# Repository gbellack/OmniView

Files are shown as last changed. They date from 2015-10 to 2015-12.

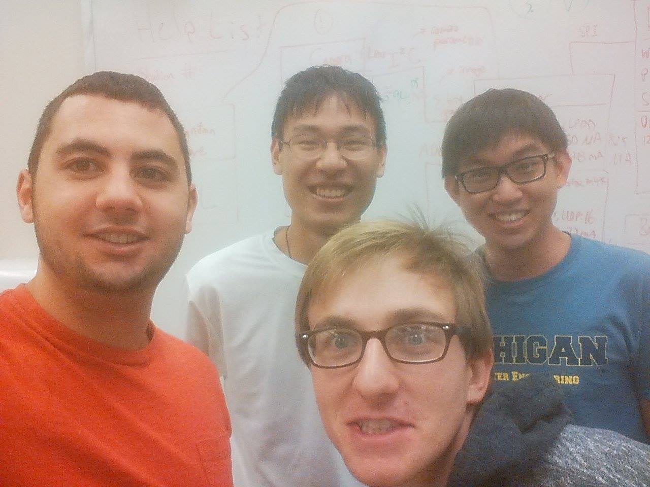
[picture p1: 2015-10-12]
face_software/testPics/fourFaces.jpg

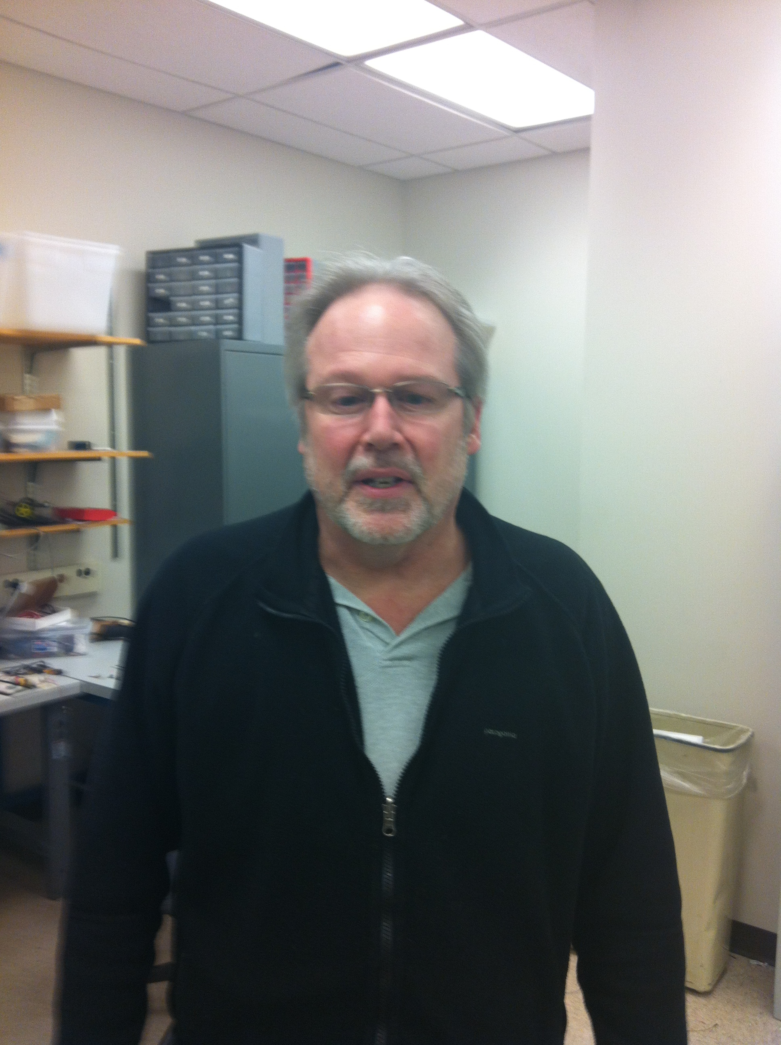
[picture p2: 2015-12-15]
face_software/training/Matthew Smith/IMG_0660.JPG

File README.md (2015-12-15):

#OmniView

##Hardware
--------
1. Texas Instruments CC3200 MCU

##Installation
1. You will need Code Composer Studio (CCS) version 6.1.1 installed on your computer. You can download this from TI's website. You will need to enter some credentials and get approved to be able to download the software.
2. You will be prompted to select modules that you want CCS to download. Please install the CC3200 package under SimpleLink Wifi Support tools.
3. After installing CCS, please install the CC3200 SDK from Texas Instruments.
4. If you launch Code Composer Studio for the first time, it will prompt you for a workspace directory. Feel free to pick a directory that you would like to work off.
5. Here comes the fun part. Please install GitHub for Windows. You will need this to pull the CCS project from this repository.  
// TODO

You should be able to build and run the project once all these are set up. 

###Flashing the program via UniFlash

If you would like to flash the program onto the Launchpad, you will need a seaparate program called Uniflash by Texas Instruments. Go ahead and download it from here and continue to follow the steps below. If you would not like to do so, you may skip them.
Credits to: [Texas Instruments Uniflash Wiki page](http://processors.wiki.ti.com/index.php/UniFlash_Quick_Start_Guide)

### Folder/File description
1. omniview/main.c : This is where the main program lies. All things related to scheduling is done here.

2. omniview/mode.c: This file contains the two modes that the facial recognition is capable of doing, as well as module initialization functions. All modules (display, camera etc.) are included and used here. Primary mode basically takes an image every second and returns the name of the person in the image.

3. omniview/pinmux.c/h : This is where we specify which pins are being used for certain protocols by the program.

4. omniview/modules folder: This stores all the modules/component libraries. More on that later...

5. omniview/modules/display/display.c/h: This file implements the driver for the display. It provides a good interface for the OLED display that we are using.

6. omniview/modules/display/buffer.c: This file contains the display buffer. The reason why we have this in a separate file is because the display had initialization values that we wanted to keep, and by adding this huge buffer definition in our display function, it will make that file really big and hard to read. Hence, we decided to split it into a separate file and link it up.

7. omniview/modules/display/font.c: This file contains the font settings for text on our OLED display. For the same reason above, we decided to move it to a separate file.

8. omniview/modules/interrupts/button_interrupt.c/h: These files contain interfaces for triggering a GPIO interrupt via one of our buttons. Some of the macros are linked to other macros defined by Texas Instruments.

9. omniview/modules/interrupts/timer_interrupt.c/h: These files contain interfaces for triggering a timer interrupt. This is mainly used by the microphone interface for audio recording purposes during secondary mode.

10. omniview/modules/microphone/microphone.c/h: These files contain the interfaces for the microphone.

11. omniview/modules/networking/tcp_network.c/h: These files contain the TCP networking interface required to send data/files across the network (or in our case, interact with our server).

12. omniview/modules/camera/mt9d111.c/h: These files contain the driver for the camera model that we are currently using.

13. omniview/modules/face_software/faceRec.cpp: This file contains the main server loop as well as several functions that help it in running.

14. omniview/modules/face_software/tcpClient.c/h: Houses the server side networking code used to communicate (by TCP) with the embedded device.

15. omniview/modules/face_software/wav_transcribe.py: Called by the main facial recognition loop. Communicates with google’s speech to text recognition server. Sends a string to parseName and receives names back. Sends names back to facial recognition main.

16. omniview/modules/face_software/parseName.py: Uses a natural language processing toolkit to process the string. Returns the names identified by the algorithm to wav_transcribe.

17. omniview/modules/face_software/training: Database holding our folders of faces. Test pic gets compared to this database to find the most similar face. A folder is created for each unique person in our dataset. The folder, named after the person, houses the pictures of the person inside.
Eg. omniview/modules/face_software/training/john_connolly/john1.jpg  is the first picture of John Connolly in the database.

###Speech Recognition
Please READ:
1. Make sure you have PyAudio installed.
2. All the examples are in the speech_recognition file.

###Version Control for Code Composer Studio Project
The .gitignore file on this repository should do the trick, but please:  
  
DO commit and push:  
1. .ccsproject  
2. .cproject  
3. .project  
4. .settings folder  
5. makefile.defs (if using SYS/BIOS)  

DO NOT commit and push:    
1. Release/*  
2. config/*  
3. .launches/  
4. .xdchelp  

Credits to: [Texas Instruments Wiki page](http://processors.wiki.ti.com/index.php/Source_control_with_CCS)  

##Support
Please feel free to contact any of us if you have any questions or concerns.

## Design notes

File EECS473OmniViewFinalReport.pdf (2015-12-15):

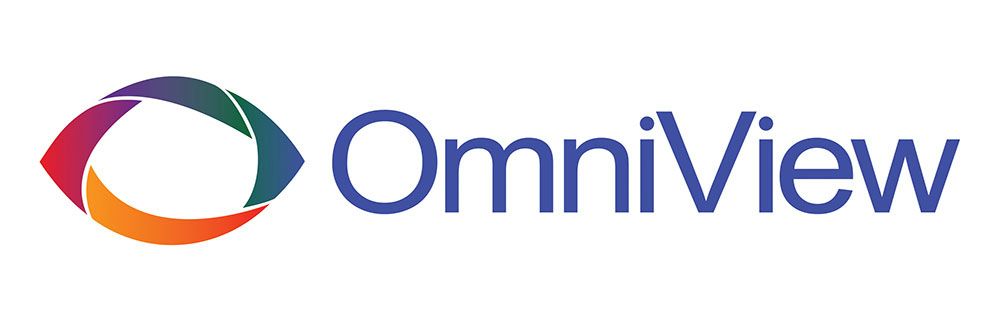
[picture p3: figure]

# Final Report

To: | Mark Brehob Eric Kumpf
From: | Garrison Bellack (gbellack), Computer Engineer John Connolly (johnconn), Computer Engineer Loren Wang (wloren), Computer Engineer Tzu-Fei Yu (tzufeiy), Electrical Engineer Zheng Hao Tan (tanzhao), Computer Engineer

Date: December 14, 2015

# OmniView Face Recognition Glasses EECS 473 Fall 2015

I. Introduction and overview of project

Foreword
Since the beginning of human interaction, names have played a crucial role. Names serve as an identifier for a person, and without them people have no identity. In our modern society dominated by social media, interactions have become more frequent but less substantial, which has sparked a phenomenon where it has become harder to remember people’s names. One of the most important things in the social world is remembering people's names. To quote Dale Carnegie, “A person’s name is to him or her the sweetest and most important sound in any language”. However, too often we can’t remember the names of people we meet, even after multiple interactions.

We decided to address this issue by applying it alongside the recent surge in popularity of smart, wearable tech. We created OmniView, a pair of smart glasses with facial recognition capabilities, that can serve as an aid to the user in identifying a person and their name. The purpose of this report is to provide a detailed description of our project, as well as detail our experiences and what we have learned. This report will be written with concurrent engineers and managers in mind to ensure the results of our project are accessible to a larger audience.

Summary
At the College of Engineering Design Expo, we proudly presented OmniView with its two modes, primary and secondary. Primary mode is the normal mode of operation which displays people's names. Secondary mode adds new people to the database by recording their introduction then storing their parsed name along with their picture. However, due to how loud it was in the Expo, we could only demonstrate primary mode. We would give OmniView to people who stopped by our booth and as soon as they put it on, they could tell each of the group members’ names by looking at us. OmniView is innately demoable and people were very impressed by the project.

We used open source facial recognition software to identify people. The project, OpenBR, is available for download . To parse people’s names we first used Google’s speech to text api to

1 | 2

1 http://openbiometrics.org/
2 https://www.google.com/intl/en/chrome/demos/speech.html

# OmniView Face Recognition Glasses EECS 473

## Fall 2015

convert the audio into words. From there we used NLTK (Natural Language ToolKit) to detect

3
if there were any names in the words spoken.

This report describes the resources used and tasks completed for this project. Below are our goals for OmniView. All Milestones were met.

Design Criteria | Importance | Likelihood | Finished State

Facial recognition correctly determines new/old faces >

80% | Fundamental | Will | Yes. > 90% facial recognition
OLED displays name and info quickly enough such that user will not have to wait | Fundamental | Expect | Yes. Recognition in < .20 seconds
Battery life > 1 hour | Important | Will | Yes. Battery life > 5 hours
User has simple/efficient control of the glasses | Important | Will | Yes. Single push button control
Weight should not exceed such a limit that it will cause pain or discomfort to the user | Important | Expect | Mostly. Initial prototype had unbalanced weight
Software & Microphone are able to capture and person’s name | Optional | Stretch | Mostly. Next iteration will have a more sensitive microphone.
Flexible PCB | Optional | Stretch | No. Decided not to use a flexible PCB.

3 http://www.nltk.org/

# OmniView Face Recognition Glasses EECS 473

## Fall 2015

II. Description of project
Our goal was to create a device that aids people in remembering names. We believe this product could see widespread casual use, but would be especially useful for people with a bad memory or those entering a large/new social environment such as school, work or a party. We believe it will be used in these situations because the price of not remembering someone’s name can be quite high. Especially in business, where having positive work relationships is critical, a lapse in social graces could mean a very real financial setback.

We thought that the optimal way to accomplish this goal is through a device like Google Glass. A small camera can be used to take pictures of whomever the device wearer is looking at, and a display near the eye can be used to alert the wearer of the person’s name. From this idea, OmniView was born.

OmniView is a pair of glasses with a camera that can instantly display the name of the person you are looking at. Using an existing database of facename pairs such as a school registry, the glasses could take a picture of the person you are looking at and send the data to a server where the person’s unique facial structure is analyzed. The server would then return the name of the matching entry, showing the name of the person in front of you on a display in the corner of your vision. A new entry could also be dynamically created by taking a picture and sending that information to the server along with accompanying audio of their introduction or only sending the picture and adding their name to the server later. This sort of solution could be very helpful in new social settings, where it can be difficult to remember the names of many new people, or in scenarios where an old acquaintance’s name is suddenly forgotten.

With our monetary and time budgets, we have accepted that it is impossible to make OmniView subtle enough to be unnoticeable. In the end, we had great success on the technical side of our project, and succeeded in implementing all of the functionality we sought to. Even with this success, our work is not done. With wearable devices, there are important concerns beyond the technical details. It is not yet socially acceptable to walk around wearing a piece of tech on your face. While we thought that OmniView could be immensely valuable if executed properly, we are also worried about the complexity of the project. The idea is in a lot of ways, a minimalist Google Glass, and so we were worried that we wouldn’t be able to complete all of our goals in the timeframe allotted. Even Google has run into issues with their wearable product. The bulkiness of Glass is an issue that prevents widespread use of the device. It is far too obvious that someone is wearing Glass, and this bothers people. Those some complaints can be applied to OmniView – our device is too heavy and intrusive to be comfortably worn. All of this led us to

# OmniView Face Recognition Glasses EECS 473

## Fall 2015

determine that OmniView as a technical project is feasible, but OmniView as a commercial product is not feasible yet.

ii. Describe the system architecture, including a detailed block diagram (not drawn by hand) of the system including peripherals, processors and the like. Give an explanation of how the architecture works – what the function of each of the devices is and how you communicate to them.

OmniView is comprised of a few submodules: A camera, a microcontroller, a display, a microphone, and a web server. The interactions between these five components powers OmniView, and can be seen in Figure 1. At a high level, the application runs by taking a picture, sending it to the web server, waiting to receive a response from the web server, and writing that response onto the display.

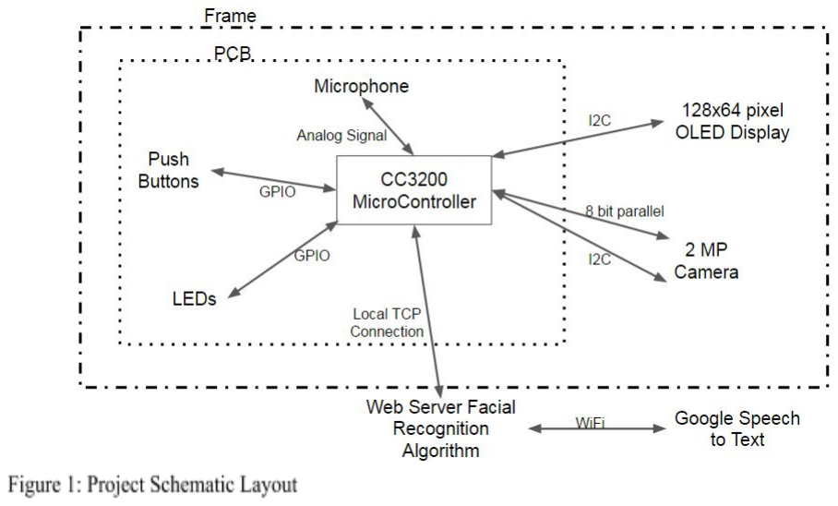
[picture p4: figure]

The first module that will be discussed is the camera. The camera is the lynchpin of OmniView; it provides the images that OmniView compares to the facename database, so that the application can determine the names of people the device wearer is interacting with. We chose to use the MT9D111 camera for this application. This camera has 2 Megapixel image quality, and communicates with the microcontroller through I2C and an 8-bit parallel databus. The I2C line is used to configure the camera, while the 8-bit parallel bus is used to transfer the

# OmniView Face Recognition Glasses EECS 473 Fall 2015

actual image from camera to microcontroller. The microcontroller polls the camera once every two seconds, receiving a fresh image and then sending it to the web server at these times.

The web server is used to perform the facial recognition algorithm and query the database of facename pairs. Using an external server and database allows us to reduce the amount of computations needed to be performed by OmniView. This plays an important role in extending the battery life of the application. Hosting the facial recognition algorithm on the server also allowed us to run the application loop very quickly. This is because the processor of the server is much better than that of our device. We relied on an opensource software for our facial recognition, with good results. Facial recognition using openBR[1], an opensource image processing library, was about 85% accurate. openBR uses the eigenfaces algorithm, a derivative of PCA (principle component analysis) method of machine learning to recognize the faces. The server code starts by initializing all the pictures in the existing database in a process known as “enrollment”. This extracts the main features of every picture. Doing this enrollment process before communicating with the device allows us save an extreme amount of time during our main application loop, allowing us to run at an O(1) speed. This is to say that the number of pictures in the database increases the initialization time of the algorithm, but has very little effect on the main loop. Once this process is done, the server connects to the TCP socket initialized by the embedded device. With a wireless connection established, the server can now receive a picture. The picture is saved onto the server, and also enrolled by the algorithm. This allows it to be compared with the existing pictures in the database, and a similarity score is assigned to each pair. The name of the face that was closest to that of the new picture is then sent through the TCP connection back to the device.

The communication between the server and microcontroller is conducted using WiFi. This is done for two reasons: it expands the maximum communication distance between the server and the device, and it allows for a higher throughput of data. Images are fairly data intensive, and we want the latency between an image sent to the server and the corresponding text sent back to the microcontroller to be as short as possible. Using WiFi does introduce at least one added layer of complexity to the device: the registering of the device as a station in a network. Instead of creating a dedicated user interface on the glasses for setting up connectivity, we instead allow for OmniView to be connected to as an access point, and communicate with a user’s personal computer. Through this method, OmniView can be registered on the network through the use of a personal computer.

# OmniView Face Recognition Glasses EECS 473 Fall 2015

We chose to use TI’s CC3200 microcontroller as the onboard processor for OmniView. This microcontroller has a dedicated core that implements the WiFi WLAN and TCP/IP stacks. It also has an onchip 80 MHz Cortex M4 processor to perform other application logic and interface with peripherals. The microcontroller includes 2 UART modules, 1 SPI module, 1 I2C module, and an 8-bit parallel camera interface. We decided on the TI CC3200 because it has built in support for a 2 megapixel camera and a core that handles the WiFi protocol. OmniView is very space constrained, because it is worn on the face. Having a chip that can handle WiFi and natively communicate with a camera is the best solution for a spaceconstrained system, because it allows us to avoid introducing even more chips into the system to handle WiFi and camera communication. Another important reason for using a chip that includes everything we needed is that the vendor (Texas Instruments) provided sample code for implementing WiFi on the microcontroller. We relied heavily on this sample code during the course of the project in order to reduce development time. If we used a dedicated WiFi module, it is unlikely that we would be able to find sample code ported to our specific microcontroller.

We decided to use an Organic Light Emitting Diode (OLED) display as an interface to the user. This is the medium through which OmniView shows the device wearer people’s names. OLED displays require less power than other common display solutions. OLED displays only draw power based on the sections of the display that are lit. Another important factor is weight of the display; OLED displays are lighter than LCDs. Communication between the display and the microcontroller is done via a common serial protocol. OLED displays in our size range support I2C, SPI, or both. Our system requirements make it impossible to use SPI as means of communication, simply because we do not have enough pins. For this reason, we use the same I2C port that the camera uses to communicate to the display.

# OmniView Face Recognition Glasses EECS 473 Fall 2015

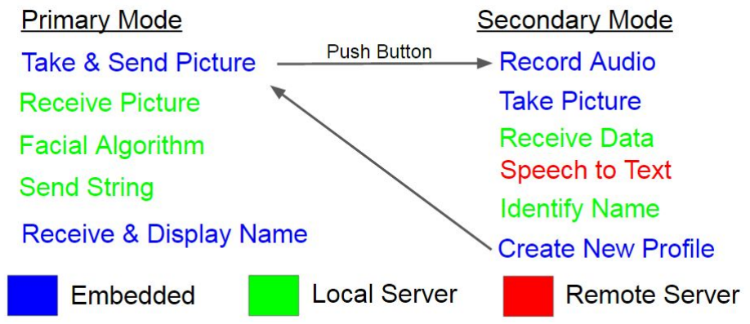
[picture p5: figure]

The microphone and push button are the parts of the system used to implement the secondary mode of operation for OmniView. The secondary mode of operation is used to dynamically add a facename pair to the database. The push button is used by the user to switch OmniView from primary to secondary operation. Once secondary mode is activated, the device then grabs data from the microphone for 10 seconds, and then captures an image of who the device wearer is looking at. OmniView then transmits that data to the web server. The web server then parses that microphone data and determines which name was spoken during that period and associates it with the image that was sent with the microphone data. Parsing text from speech is a nontrivial task, and for this reason, we employed Google Speech[3] to convert the data from audio to text. After this was completed, the text was piped to a natural language toolkit (NLTK) that was hosted on the external server. This allowed us to pick out any proper nouns that existed in the sentence. These nouns were assumed to be the name of the person in the picture, and a folder was created for this new entry.

OmniView Face Recognition Glasses | EECS 473 Fall 2015
III. | Milestones, schedule and budget

We stuck to our original schedule pretty well through the project development cycle. There were multiple tasks that were shifted around the timeline, such as ordering components, which we wanted to order by late September but did not do so until mid November. This was rather trivial as we didn’t know what we need on our PCB to get the components to work. We also started working on the microphone about a week in advance, since we were fairly certain that a stretch goal is plausible based on our progress before Thanksgiving break. We also added a few more tasks, such as spinning out a separate sandwich board just in case we needed it. We provided more details about this below.

These were the milestone deliverables that we signed up for during the project proposal stage:

Milestone 1:

Tasks | Outcomes
Prototype is capable of displaying meaningful text on the OLED display. | On time.
Basic WiFi module is able to send/receive data from server. | On time.
PCB schematic design should be done. | We finished the PCB schematic design about 24 hours earlier, but the peripheral board wasn’t done until 2 days later because we didn’t expect it to take so much time. We were kind of ambitious of getting this done by the time allocated.
The image recognition algorithm should already be implemented and able to show meaningful information. | This was mostly done by the time the project proposal was due.

# OmniView Face Recognition Glasses EECS 473 Fall 2015

Milestone 2:

Tasks | Outcomes
PCB should have been ordered by now. | We were about 24 hours late for this because we have having some doubts about our main board layout. Fortunately, we pushed this back and managed to fix them before we ordered them.
The OLED display and WiFi software should be finished with only minor bugs left. | On time.
Have decided on whether we want to implement functionalities related to the microphone. | On time.
Frame of glasses should be 3D printed by now. | We decided to put this task till later because during this stage of the project, we were running into issues with our CC3200MOD package. We felt that we needed the extra manpower (Tzu-Fei) to come over and help us desolder/resolder until we can successfully program the board. We eventually finished it after 4 days from the proposed deadline.

OmniView Face Recognition Glasses | EECS 473 Fall 2015
IV. | Lessons learned
| What went well? What went poorly? If you could send a short memo back in time to your group when you first started, what would it say? What technical material do each of you feel you’ve learned from the project?

Over the course of the project, we have learned a lot about what it takes to create a complex embedded system. There is a design phase – where components and tools are chosen for the system. Next there is a development phase – where the idea begins to be actualized. Then comes the assembly phase – where each module is integrated into the finalized system. We learned a lot about the design and assembly phases of embedded system on the way to our finished project.

The most important lesson learned is that the design phase is the most important part of system implementation. There is a very real possibility that an idea will have to be completely reworked in the prototype phase when the engineer realizes that the design isn’t feasible. Every stage of the project needs to be properly thought out. If there is even a single mistake in the design, then at best it will be a few extra hours creating a workaround for the system to function. At worst, it could mean the creation of an entirely new system.

One prime example of a mistake in the design stage leading to enormous problems down the road is an issue we had with our printed circuit board (PCB). During the schematic design of the PCB, our engineers chose to go with a package that would save us space and simplify the design process significantly. This probably resulted in 8 manhours saved in the design of the schematic and layout of the PCB. However, that part is incredibly difficult to solder. The result was an added 40 manhours spent trying to solder this component to the PCB.

A few things went very well. Using components supported by our vendor, Texas Instruments, sped up some areas of development significantly. An important reason for choosing the camera that we did is because TI has sample code for interacting with this device. Cameras are relatively complex, and choosing to use a camera that had the interfacing done for us was a huge boon. Having everything incorporated into our microcontroller was a major factor in our completing the software development on time. This allowed us to spend more time working through the unexpected issues that arose in the project, such as the PCB soldering issue described above. Another such unexpected issue was the difficulty we had working with TI’s code. While there was plenty of sample code provided for us, it was extremely difficult to follow, and some of the

# OmniView Face Recognition Glasses EECS 473 Fall 2015

sample applications TI are not well documented. For instance, one sample application instructs users to use “the browser of her choice” to connect to the microcontroller. We have found that Chrome, Firefox, and Internet Explorer are not compatible with this sample application, and when we tried to use these browsers the sample application failed. It was only through many hours of trial and error that we determined Safari to be the only browser that was compatible with the microcontroller and sample application.

We have gained a wide variety of skills from software to hardware development through the creation of OmniView. Several of our group members are now proficient in the eagle CAD tool. Beyond that, these group members have a much more solid theoretical understanding of the best practices involved with circuit board layout. We also needed to lay out a 50 ohm impedance trace for OmniView’s antenna, which was a valuable experience and gave us some insight on the different factors that affect trace impedance at very high frequencies. Another hardware related skill improved upon in this project is soldering of surface mount components. We had two PCBs to populate, with a wide variety of packages, some of them extremely difficult to solder. The positive to this struggle is that several of our team members are now extremely proficient in soldering a wide variety of surface mount components. Our group has gained experience in using large open source tools through this project as well. We used several open source tools, including openBR[1], for image analysis, and Google Speech[3] for audio processing. This project has taught us how to integrate these tools into an existing application.

The most important thing that we learned in this project is system design and architecture. In our careers as students at the university, we have never had the opportunity to design a system from top to bottom like we have in this course. The project idea and implementation are entirely up to us. Designing a system with both hardware and software components from scratch is a very difficult thing to do, because of the numerous unforeseen difficulties that arise in system design. One such difficulty is circuit board fabrication. Designing a circuit board with a CAD tool is easy enough, but fabricating the board is another matter. Usually circuit board fabrication will cost at least $100, and it takes at least a week to receive the board after an order. From a software perspective, the system becomes very complex, and larger than the software projects students are accustomed to in their classes. This project gave us experience in managing such a large system.

If we could send a memo back in time to our group, the memo would detail some architecture changes that should be made. Our choice of processor is currently in a quad flat nolead package (QFN). We made this decision because it simplified the schematic, but it raised the difficulty of our soldering job by an order of magnitude. This letter would tell our group to spend the extra

# OmniView Face Recognition Glasses EECS 473 Fall 2015

few hours using a different part in the schematic, so that we would not have to spend 50 hours soldering. In addition, the letter would detail spending a bit more time on the architecture of the system. The chip that we used, TI’s CC3200, ended up being very difficult to work with. In hindsight, it might have been worth choosing a chip from a different vendor, because of the huge amount of difficulty that we had dealing with Texas Instruments.

# OmniView Face Recognition Glasses EECS 473 Fall 2015

V. Contributions of each member of team
Team Member | Contributions | Effort
Garrison Bellack | In the early phase of the project, Garrison helped Loren in bringing up the facial recognition software on the server side. He implemented some of the TCP networking code. He then did most of the integration tasks as different components were added to the project. In other words, the interfaces were written for him, then he integrated them and debugged it. Most of the software refinements (timing constraints and requirements) during the later stage were handled by him and Loren. | 20%
John Connolly | John and Tzu-Fei did the schematic design and board layout. John also helped out with surfacemount/soldering related work. After we got the board to be programmed, he helped develop the microphone interface. He also helped the team to debug camera issues (both large and small cameras). | 20%
Loren Wang | Loren was the main guy who did server side code for both facial recognition software and natural language processing via Google Speech. He also helped the team to debug camera issues (both large and small cameras). Most of the software refinements (timing constraints and requirements) during the later stage were handled by him and Garrison. | 20%
Tzu-Fei Yu | Tzu-Fei and John did the schematic design and board layout. Besides that, he joined Zheng Hao to order the components needed. He also helped us with surfacemount/soldering work and made the 3D-printed glasses from scratch. | 20%

# OmniView Face Recognition Glasses EECS 473

## Fall 2015

Zheng Hao Tan Zheng Hao helped in the initial board bring up and setting up the toolchain (IDE + flashing software). He then worked on the display interface and helped Tzu-Fei on part selection/ordering them. He then helped out with soldering work. Once we got the board programmed, he worked on both a timer interrupt and button (GPIO) interrupt interface. The timer interrupt interface is then used by John for microphone purposes.

20%

OmniView Face Recognition Glasses | EECS 473 Fall 2015
VI. | Cost of Manufacture

The quote had failed to estimate the price for the main system board at first. After a few trials, we have determined that the minimum trace was too small (0.01mm). By carefully scanning through the board layout and fixing the width of the trace and polygon, we successfully generated a quote. According to the table below, which shows the result of the quote, the total cost for populating the whole system is about $728 if we requested only one unit. In contrast, this is below the $1000 budget that was given to us for the project. If we had limited the amount of money spent on the prototyping phase, we could afford this cost. Unless we would like to have spare ones in case the board is accidently burnt, one of each board should satisfy our application. The limiting quantity is four, where the total price for both board is $1000.75, and this will exceed our budget, leaving no room for us to prototype it.

On the other hand, one of the downsides of this is that once a mistake is unintentionally made, there will be no room to make another iteration for the PCB. Additionally, the manufacturing time is a major factor since the given project developing time span is about three months. The 22 day processing and shipping time will take up almost ⅓ of our project schedule. Furthermore, the price of the board increases dramatically if we want a faster turnaround time. The minimum manufacturing period is 8 days, and the cost for both boards is $1972.82. This price is not feasible. Most of the expenses goes to the assembly category when processing time is long, and goes to both PCB manufacture and assembly when the time is short. As a result, with the given time and budget, it is more desirable not to go with this option. Even if time allows, one would save more money without having the board house to assemble the board but doing oneself. In general, this option is not reasonable.

OmniView Main Board

Days | Quantity | PCB ($) | Parts ($) | Assembly ($) | Total ($) | Unit Price ($)
22 | 1 | 57.81 | 77.43 | 290.34 | 425.57 | 425.57
22 | 2 | 57.81 | 101.13 | 308.86 | 467.79 | 233.9
22 | 4 | 110.61 | 148.42 | 345.89 | 604.93 | 151.23
8 | 1 | 696.76 | 77.43 | 435.51 | 1209.7 | 1209.7

# OmniView Face Recognition Glasses EECS 473 Fall 2015

OmniView Peripheral Board

Days | Quantity | PCB ($) | Parts ($) | Assembly ($) | Total ($) | Unit Price ($)
17 | 1 | 15.32 | 65.65 | 222.28 | 303.24 | 303.24
17 | 2 | 15.32 | 81.29 | 234.71 | 331.31 | 165.65
17 | 4 | 25.63 | 110.61 | 259.00 | 395.82 | 98.955
7 | 1 | 364.05 | 65.65 | 333.42 | 763.12 | 763.12

# OmniView Face Recognition Glasses EECS 473 Fall 2015

VII. Parts

Budget

The items and price are listed in the table below:

Item for prototyping | Quantity | Total Cost ($)
OLED display Breakout board | 4 | 78.00
TI CC3200 LAUNCHXL Development board | 2 | 66.98
TI CC3200 MOD Development board | 1 | 34.99
TI CC3200 Camera Booster Pack | 2 | 44.49
MT9D111 Camera Breakout | 2 | 33.2
Microphone Breakout | 1 | 7.95
Item used on final product | Quantity | Total Cost ($)
LDO regulators (3.3V, 2.8V, 1.8V) TPS79328DBVRG4 TPS79318DBVR TPS73733DCQ | 20 | Free
MT9D111 Camera (flex module) | 5 | 24.66
AVX 145602030000829 | 10 | 8.80
OLED Module | 4 | 25.23
PCB Main Board | 2 | 152.03
PCB Peripheral Board | 2 | 86.03
PCB Sandwich Board | 3 | 4.05
TI CC3200 MOD MCU | 5 | Free

OmniView Face Recognition Glasses | EECS 473 Fall 2015
TI CC3200R1M2RGC | 3 | 31.37
Glasses Frame | 2 | Free
Lens | 1 | 10.99
Passive components (Capacitors, Resistors, Inductor, LEDs, Cable, Connectors, ferrite beads, uFL connector, button switch, pin head, ribbon cable, wires, Amplifier MAX9814, Microphone electret CMA-4544PF-W) | | 90.00
Lipo Battery Charger | 3 | 23.85
Lipo Battery 850mAh | 2 | 19.90
Lipo Battery 500mAh | 1 | 7.95

The total expenditure for this project is $751.47.

# OmniView Face Recognition Glasses EECS 473 Fall 2015

VIII. References and citations

Our main repository is split into two sections, one of them is the firmware for the facial recognition glasses and the other is server side code. Here is a brief overview of how we laid out the main repository, as well as the files and interfaces for the components that we use.

omniview/main.c :

This file contains the main function and several initialization functions for the facial recognition glasses.

#define FACE_RECOGNITION_TASK_NAME "FaceRecognitionTask"

#define FACE_RECOGNITION_TASK_STACK_SIZE 8192

#define FACE_RECOGNITION_TASK_PRIORITY 2

// EFFECTS: Initializes the board.
static void InitializeBoard();

omniview/mode.c:

This file contains the two modes that the facial recognition is capable of doing, as well as module initialization functions. All modules (display, camera etc.) are included and used here. Primary mode basically takes an image every second and returns the name of the person in the image.

// EFFECTS: A freeRTOS task that runs the facial recognition mode. This periodic task is scheduled to run every second.
void FaceRecognitionMode(void *pvParameters);

omniview/pinmux.c:

This file is originally provided by Texas Instruments in their sample applications, and it contains the pin configuration and modes for the facial recognition glasses. We have modified it extensively to fit our pinout requirements.

// EFFECTS: Configures the pinout for this project.

# OmniView Face Recognition Glasses EECS 473

## Fall 2015

void PinMuxConfig(void);

omniview/modules/display/display.c + omniview/modules/display/display.h:

These files contains the OLED display interface.

#define SSD1306_I2C_ADDRESS 0x3C // 011 110+SA0+RW, SA0 is grounded.

/* PIN LAYOUT CONFIGURATIONS */

#define DISPLAY_RESET_PIN 0x10 /*gpio 28 for display reset */

/* OLED CONFIGURATIONS */

#define SSD1306_LCDWIDTH | 128 | /* Display width */

#define SSD1306_LCDHEIGHT | 64 | /* Display height */

#define SSD1306_SETCONTRAST | | 0x8100

#define SSD1306_DISPLAYALLON_RESUME | 0xA400

#define SSD1306_DISPLAYALLON | | 0xA500

#define SSD1306_NORMALDISPLAY | | 0xA600

#define SSD1306_INVERTDISPLAY | | 0xA700

#define SSD1306_DISPLAYOFF | | 0xAE00

#define SSD1306_DISPLAYON | | 0xAF00

#define SSD1306_SETDISPLAYOFFSET | | 0xD300

#define SSD1306_SETCOMPINS | | 0xDA00

#define SSD1306_SETVCOMDETECT | | 0xDB00

#define SSD1306_SETDISPLAYCLOCKDIV | 0xD500

#define SSD1306_SETPRECHARGE | | 0xD900

#define SSD1306_SETMULTIPLEX | | 0xA800

#define SSD1306_SETLOWCOLUMN | | 0x0000

# OmniView Face Recognition Glasses EECS 473

## Fall 2015

#define SSD1306_SETHIGHCOLUMN | 0x1000

#define SSD1306_SETSTARTLINE | 0x4000

#define SSD1306_MEMORYMODE | 0x2000

#define SSD1306_COLUMNADDR | 0x2100

#define SSD1306_PAGEADDR | 0x2200

#define SSD1306_COMSCANINC | 0xC000

#define SSD1306_COMSCANDEC | 0xC800

#define SSD1306_SEGREMAP | 0xA100

#define SSD1306_CHARGEPUMP | 0x8D00

#define SSD1306_EXTERNALVCC | 0x0100

#define SSD1306_SWITCHCAPVCC | 0x0200

/* SCROLLING DEFINES */
#define SSD1306_ACTIVATE_SCROLL | 0x2F00

#define SSD1306_DEACTIVATE_SCROLL | 0x2E00

#define SSD1306_SET_VERTICAL_SCROLL_AREA | 0xA300

#define SSD1306_RIGHT_HORIZONTAL_SCROLL | 0x2600

#define SSD1306_LEFT_HORIZONTAL_SCROLL | 0x2700

#define SSD1306_VERTICAL_AND_RIGHT_HORIZONTAL_SCROLL 0x2900 #define SSD1306_VERTICAL_AND_LEFT_HORIZONTAL_SCROLL 0x2A00

#define BLACK 0

#define WHITE 1

#define INVERSE 2

/* NAME PARAMETERS */
#define MAX_NAMES_ALLOCATED 5 #define MAX_NAME_LENGTH 15 #define NAME_TEXT_SIZE 1

# OmniView Face Recognition Glasses EECS 473 Fall 2015

#define TEXT_COLOR WHITE

/* Swaps the two values */
#define swap(a, b) { int16_t t = a; a = b; b = t; }

#define pgm_read_byte(addr) (*(const unsigned char *)(addr))

/* EFFECTS: Displays the name on the screen. */
extern void DisplayName(const char *firstName, const char *lastName);

/* Printing functions */
extern void ClearPrintDisplayLine(const char* str);
extern void DisplayPrint(const char *str);
extern void DisplayPrintLine(const char *str);
extern void PrintHelper(uint8_t c);

extern void FillRect(int16_t x, int16_t y, int16_t w, int16_t h, uint16_t color);
extern void DrawFastVLine(int16_t x, int16_t y, int16_t h, uint16_t color);
extern void DrawFastVLineInternal(int16_t x, int16_t __y, int16_t __h, uint16_t color); extern void DrawFastHLineInternal(int16_t x, int16_t y, int16_t w, uint16_t color);

extern void DrawChar(int16_t x, int16_t y, unsigned char c, uint16_t color, uint16_t bg, uint8_t size);
extern void SetCursor(int16_t x, int16_t y);
extern void SetTextColor(uint16_t c);
extern void SetTextSize(uint8_t s);
extern void SetTextWrap(uint8_t w);

/* EFFECTS: Changes to new line */ extern void IncrementLine();

/* REQUIRES: The reset pin.
* EFFECTS: Initializes the display pins.
*/
extern void InitializeDisplay();

/* EFFECTS: Send and receive the payload */

# OmniView Face Recognition Glasses EECS 473 Fall 2015

extern void Send(uint16_t payload);

/* Display */

/* EFFECTS: Clears the display. */
extern void ClearDisplay();

/* EFFECTS: Displays whatever that is stored in buffer */ extern void Display();

/* EFFECTS: Dims the display */
extern void Dim(int dim);

/* EFFECTS: Turns the display on. */ extern void DisplayOn();

/* EFFECTS:d Turns off the display. */ extern void DisplayOff();

/* Scrolling */

/* EFFECTS: Sets the scroll direction */
extern void StartScrollRight(uint8_t start, uint8_t stop);

extern void StartScrollLeft(uint8_t start, uint8_t stop);

extern void StopScroll();

/* REQUIRES: the x, y, and color.
* EFFECTS: Sets a pixel.
*/
extern void DrawPixel(int16_t x, int16_t y, uint16_t color);

omniview/modules/display/buffer.c:

# OmniView Face Recognition Glasses EECS 473

## Fall 2015

This file contains the display buffer. The reason why we have this in a separate file is because the display had initialization values that we wanted to keep, and by adding this huge buffer definition in our display function, it will make that file really big and hard to read. Hence, we decided to split it into a separate file and link it up.

static uint8_t buffer[SSD1306_LCDHEIGHT * SSD1306_LCDWIDTH / 8] = ….

omniview/modules/display/font.c:

This file contains the font settings for text on our OLED display. For the same reason above, we decided to move it to a separate file.

/* This file contains the font used in printed text. */

// Standard ASCII 5x7 font
static const unsigned char font[] = ...

omniview/modules/interrupts/button_interrupt.h + omniview/modules/interrupts/button_interrupt.c:

These files contain interfaces for triggering a GPIO interrupt via one of our buttons. Some of the macros are linked to other macros defined by Texas Instruments.

/* This is the amount of time to count to account for button debouncing. */
#define BUTTON_DEBOUNCE_THRESHOLD 4

/* This determines the button interrupt priority */
#define BUTTON_INTERRUPT_PRIORITY 10

/* Macros for interrupt button pins */
#define INTERRUPT_BUTTON_PIN | PIN_01

#define INTERRUPT_BUTTON_GPIO_PIN | GPIO_PIN_2

#define INTERRUPT_BUTTON_BASE_ADDR | GPIOA1_BASE

#define INTERRUPT_BUTTON_GPIO_HW_INT | INT_GPIOA1

/* EFFECTS: Initializes all the interrupts used in this application */

# OmniView Face Recognition Glasses EECS 473 Fall 2015

extern void InitializeInterrupts();

/* EFFECTS: Disable and unregister all interrupts */
extern void DeinitializeInterrupts();

/* EFFECTS: Toggles the mode based on button press (ISR) */ static void ButtonPressIntHandler(void);

omniview/modules/interrupts/timer_interrupt.h + omniview/modules/interrupts/timer_interrupt.c:

These files contain interfaces for triggering a timer interrupt. This is mainly used by the microphone interface for audio recording purposes during secondary mode.

#define TIME_IN_MSECS 100

#define SAMPLE_RATE 10000

#define MIC_SAMPLE_SIZE 2

/* EFFECTS: Initializes Timer A and enables it */
extern bool recordingDone;

extern void TimerConfigNStart(uint32_t sampleRequest, char *buf);

extern uint32_t currentSamples;

/* EFFECTS: Deinitializes Timer A and unregisters it */
extern void TimerDeinitStop();

/* EFFECTS: Timer Interrupt handler */
extern void TimerPeriodicIntHandler(void);

omniview/modules/microphone/microphone.h + omniview/modules/microphone/microphone.c:

// EFFECTS: This function accepts a pointer to a buffer

# OmniView Face Recognition Glasses EECS 473 Fall 2015

//and the number of seconds of recording is desired
//and fills the buffer with microphone data
//it returns the number of bytes of data stored in the buffer.
//The current system is set up to record 10000 samples per second. //this corresponds to 20000 bytes per second
// some common values of numSeconds
// milSec = 1000 > 20000 bytes
uint32_t GetAudio(char * buf, int milSec);

// EFFECTS: Grabs an ADC sample
inline uint16_t GetMicSample();

// EFFECTS: Initialize the ADC associated with the microphone, must be called before //you do any mic stuff
void InitializeMicrophone();

omniview/modules/networking/tcp_network.h + omniview/modules/networking/tcp_network.c:

These files contain the TCP networking interface required to send data/files across the network (or in our case, interact with our server).

extern int InitTcpServer(unsigned short port);

extern void SendInt(int sockID, int num);

extern void TakeAndSendPicture(int sockID);

extern void TakeAndSendRecording(int sockID, int milSec);

extern void ReceiveString(int sockID, char* stringBuf, int bufSize);

void Delay(int count);

void WaitForAck(int sockID);

# OmniView Face Recognition Glasses EECS 473 Fall 2015

void SendData(int sockID, UINT8* fileData, int fileSize);

void SendFile(int sockID, UINT8* fileData, int fileSize);

omniview/modules/camera/mt9d111.h + omniview/modules/camera/mt9d111.c:

These files contain the driver for the camera model that we are currently using.

long CameraSensorInit();

long StartSensorInJpegMode(int width, int height);

long CameraSensorResolution(int width, int height);

omniview/modules/camera/i2cconfig.h + omniview/modules/camera/i2cconfig.c:

These files contain the I2C interface for the camera.

unsigned long I2CInit();

unsigned long I2CBufferRead(unsigned char ucDevAddr, unsigned char *ucBuffer, unsigned long ulSize,unsigned char ucFlags);

unsigned long I2CBufferWrite(unsigned char ucDevAddr, unsigned char *ucBuffer, unsigned long ulSize,unsigned char ucFlags);

omniview/modules/camera/camera_app.h + omniview/modules/camera/camera_app.c:

This file contains the high level interface for camera functions.

void InitCameraComponents(int width, int height);

void CamControllerInit();

unsigned short StartCamera(char **WriteBuffer);

# OmniView Face Recognition Glasses EECS 473 Fall 2015

long SetCameraResolution(int width, int height);

SERVER SIDE CODE

omniview/modules/face_software/faceRec.cpp
This file contains the main server loop as well as several functions that help it in running.

//Adds new value to buffer and returns the name that holds the majority in the buffer
string majority(string new_val);

//Facial recognition algorithm returns the file path of the picture with the closest similarity to the captured image. This function extracts the name of the person from the filepath. (The image resides in a folder named after the person).
void extractName(double score, QString file_input);

//Runs the main loop for facial recognition. Inits tcp socket and database of pictures. Waits for tcp message, which determines whether to run primary or secondary mode. Primary mode runs the main facial recognition algorithm with the received picture, and sends the detected name back to the server. Secondary mode receives data, and sends audio to wav_transcribe.py. This will return a string with the processed name, and create a new folder with the picture and name. int main();

omniview/modules/face_software/tcpClient.cpp + omniview/modules/face_software/tcpClient.h

Houses the server side networking code used to communicate (by TCP) with the embedded device.

//initializes the socket number to the same number as on the device
void initSocket(int& sockfd);

//sends a string to the device
void sendString(int sockfd, string str);

//main receive loop, receives raw data bytes from the device int recvMain (int sockfd);

# OmniView Face Recognition Glasses EECS 473 Fall 2015

omniview/modules/face_software/wav_transcribe.py
Called by the main facial recognition loop. Communicates with google’s speech to text recognition server. Sends a string to parseName and receives names back. Sends names back to facial recognition main.

omniview/modules/face_software/parseName.py
Uses a natural language processing toolkit to process the string. Returns the names identified by the algorithm to wav_transcribe.

omniview/modules/face_software/training
Database holding our folders of faces. Test pic gets compared to this database to find the most similar face. A folder is created for each unique person in our dataset. The folder, named after the person, houses the pictures of the person inside.
Eg. omniview/modules/face_software/training/john_connolly/john1.jpg is the first picture of John Connolly in the database.

# OmniView Face Recognition Glasses EECS 473 Fall 2015

OmniView Main Board

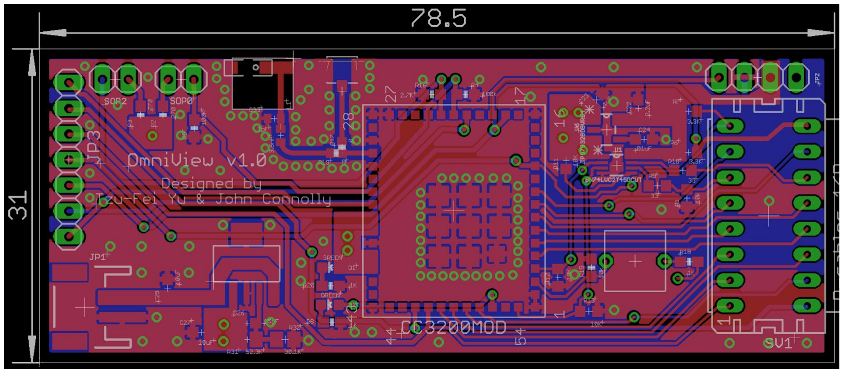
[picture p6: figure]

# OmniView Face Recognition Glasses EECS 473 Fall 2015

OmniView Peripheral Board

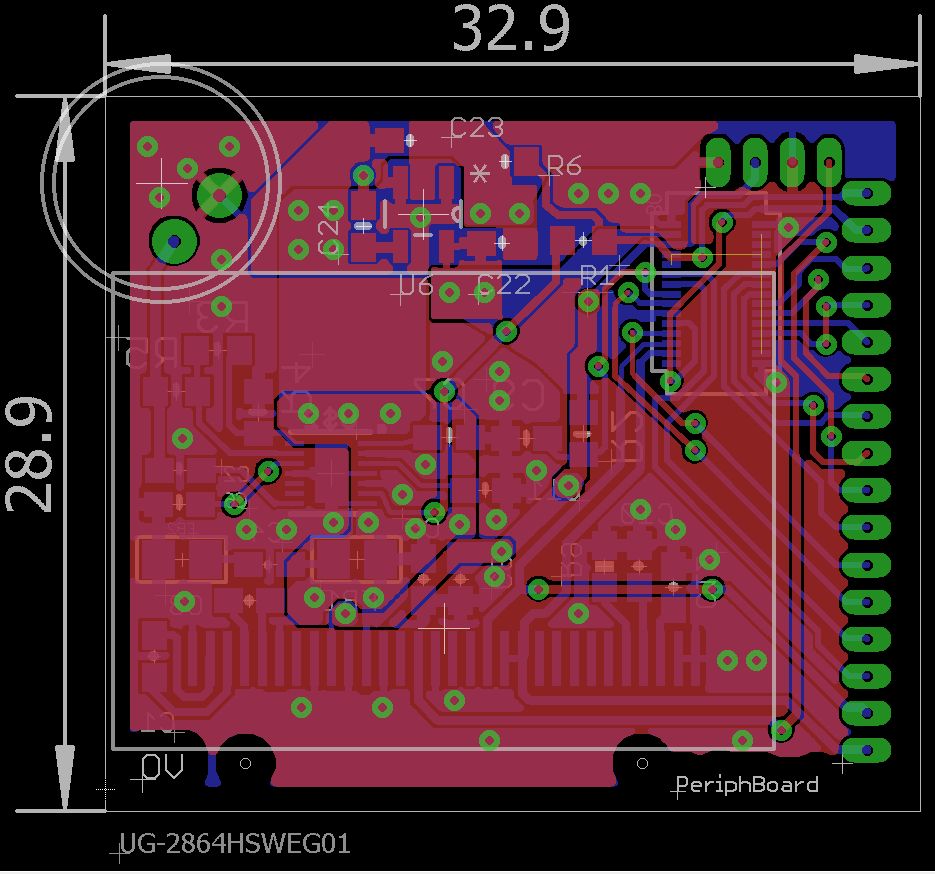
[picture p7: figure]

# OmniView Face Recognition Glasses EECS 473 Fall 2015

Display (SSD1306 126x64 OLED Display):

We bought a display breakout board from Adafruit and we were thankful that there is pre written library for Arduino on GitHub . Nevertheless, there was a fair amount of work trying to

4
port it over to our project. For example, some of the Arduino library calls were not given, and since this particular library is a subclass of another Adafruit library that handles graphics on displays, we had to merge them together. I2C functions were designed differently on both platforms, and we had to move data bits and send them in chunks as opposed to Arduino’s append style function calls. Hence, there were some logic that was modified to get this to work. Besides that, we did not have a delay function in our platform, and this required us to manually calculate and implement them based on clock cycles.

Camera (MT9D111):

There were limited cameras that were compatible with our CC3200 microprocessor, and since Texas Instruments had sample applications (and some libraries) for the MT9D111 camera, we decided to use it for OmniView. However, we had to decouple dependencies on our camera, as well as fix some of the timing constraints that TI violated in their drivers. For example, they did not follow the hard reset timing guidelines on the datasheet, and that caused us some trouble when we were debugging the smaller camera. On our final PCB, we were using a smaller version of the MT9D111, and it took us a day to realize that the slave address is different than the larger camera (0x90 as opposed to 0xBA). Although they have the same model numbers, our smaller camera had issues when the internal clock is enabled despite us not using it at all. The library had to be modified to fit our needs.

Microphone:

We purchased a breakout board from Adafruit, and there were several sample application on how to use them. Since the interface was fairly trivial, we implemented them from scratch for our own application.

MCU (CC3200MOD):

Since we went for the CC3200MOD, we were lucky enough to find someone who did some of the CC3200MOD pin layout for us . Other than that, most of the layouts were done by hand.

5

4 https://github.com/adafruit/Adafruit_SSD1306 5 https://github.com/alikian/CC3200MOD

# OmniView Face Recognition Glasses EECS 473 Fall 2015

3D-printed glasses:

The 3D printed glasses and housing was designed using solidworks and printed by the makerbot in the mesh lab. The housing for both the boards were done from scratch. However, the main frame of the glasses was taken online [6] and modified to fit our needs. Bassically, the glasses was completely redesigned but the base sketch was referenced from online sample. We measured the dimensions and eliminated the unnecessary parts to reduce weight. Knobs and matings are added so that the frame is able to hold our housing and it can be printed separately.

Others:

There were some sample applications that used timer and GPIO interrupts, and we were able to understand and port them over to our application. All the pins and timing constraints had to be changed, but the basic idea of initializing, enabling, clearing and disabling them were taken from some of the examples given. In other words, there were good wrappers/interfaces provided by TI for handling interrupts.

[1] http://openbiometrics.org
[2] http://www.nltk.org
[3] https://www.google.com/intl/en/chrome/demos/speech.html
[4] http://www.imagemagick.org/script/index.php
[5] http://sox.sourceforge.net/
[6] https://grabcad.com/library/software/solidworks/tag/glasses

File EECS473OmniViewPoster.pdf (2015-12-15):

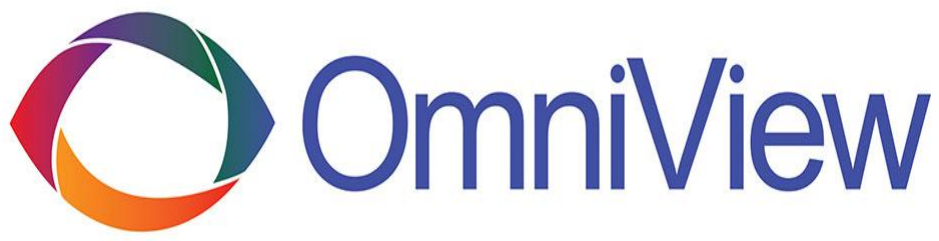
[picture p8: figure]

# OmniView: The Future of Glasses

# EECS 473 Senior Design Project

John Connolly Zheng Hao Tan Garrison Bellack | Loren Wang | Tzu-Fei Yu
Design Inspiration | Implementation

### Server Side

### Embedded Software

Since the beginning of human interaction, people have
struggled to remember names. For this reason, our group created a head worn device, capable remembering those names for you.

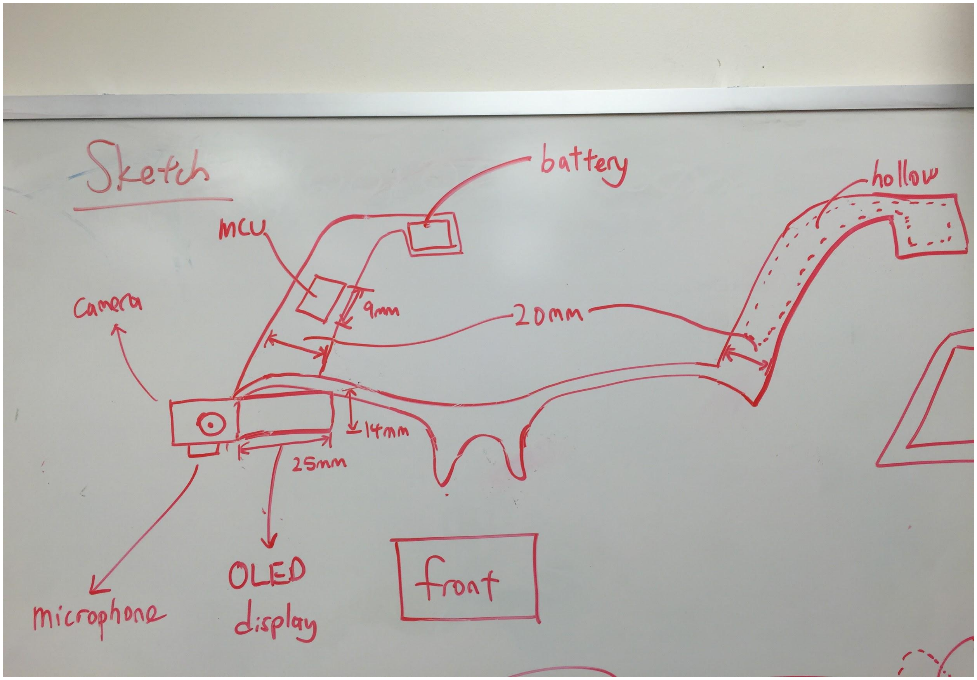
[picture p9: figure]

## Potential Market

The server software houses the facial recognition algorithm and natural language processing unit, as well as the database of stored faces. It connects to OmniView through WiFi and waits for a picture. Once it receives a picture, the server responds back with the matching name which OmniView displays.

### Goals and Planning

Figure 3: Design Schedule Plan

CC3200
MicroController

Microphone

Push
Buttons

LEDs

Web Server Facial
Recognition
Algorithm

128x64 pixel
OLED Display

2 MP
Camera

Local TCP
Connection

GPIO

GPIO

Analog Signal

8 bit parallel

I2C

I2C

PCB

Frame

Google Speech
to Text

WiFi

Figure 1: Original sketch of OmniView

Figure 6: Hardware Schematic Layout

Our design goals were to stay small, lightweight, and power-efficient. Eventually we decided on TI’s CC3200 microcontroller. The microcontroller contains an ARM Cortex M4 processor and an on-board wi-fi module which we use to connect to the server. The I2C lines are used to connect to both the camera and display. The camera has a resolution of 2MP while the display

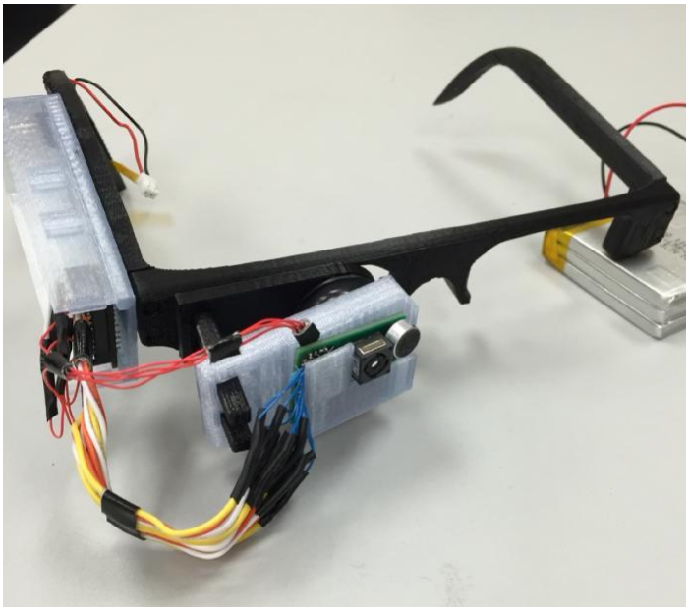
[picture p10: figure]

contains 128x64 pixels. Figure 2: Finished Project

OmniView has two modes, primary and secondary. Primary mode is the normal mode of operation which displays people's names. Secondary mode adds new people to your database by recording their introduction then storing their parsed name with their picture.

### Hardware

We prioritized scheduling hardware first due to the turnaround time in obtaining our PCBs from the manufacturer. We aimed to finish a week prior to the final due date to allow us to debug any remaining issues.

Primary Mode | Secondary Mode

Receive Picture

Take & Send Picture

Receive & Display Name

Facial Algorithm
Send String

Record Audio
Take Picture
Receive Data
Speech to Text

Create New Profile

Identify Name

Embedded | Local Server | Remote Server

Figure 4: OpenBR Facial Recognition Algorithm

We believe this product could see widespread casual use but is especially useful for people entering a large or new social environment. A prime example would be a teacher using OmniView to learn all the names of his students in a new college class.

Push Button

Figure 5: Operation Modes

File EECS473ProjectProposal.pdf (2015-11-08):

## EECS 473 Project Proposal: OmniView, The Facial Recognition Glasses

Team Members:
Loren Wang, wloren
John Connolly, johnconn
Tzu-Fei Yu, tzufeiy
Garrison Bellack, gbellack
Zheng Hao Tan (Bobby), tanzhao

Executive Summary

Since the beginning of human interaction, names have played a crucial role. Names serve as an identifier for a person, and without them people have no identity. In our modern society dominated by social media, interactions have become more frequent but less substantial, which has sparked a phenomenon where it has become harder to remember people’s names. We have decided to address this issue by applying it alongside the recent surge in popularity of smart, wearable tech. We aim to create a pair of smart glasses with facial recognition capabilities, that can serve as an aid to the user in identifying a person and their name. Using a preexisting database of facename pairs, when you see a person, the glasses will recognize them even if you don’t, and display their name for you. This will help you to remember the person and boost social interaction. This implementation also provides us a platform to further expand upon, such as adding phone or social media integration for other notifications, or sending additional information about the person you are looking at into your view.

High Level Description

One of the most important things in the social world is remembering people's names. To quote Dale Carnegie, “A person’s name is to him or her the sweetest and most important sound in any language”. However, too often we can’t remember the names of people we meet, even after multiple interactions.

Our vision is to create a product, the OmniView, that aids people in remembering names. We believe this product could see widespread casual use, but is specifically useful for people with a bad memory or those entering a large/new social environment such as school, work, or a party. We believe it will be used in these situations because the price of not remembering someone’s name can be quite high. Especially in business, where having positive work relationships is critical, a lapse in social graces could mean a very real financial setback.

The requirements for this product are not that stringent. It obviously needs to be safe and manufacturable. Reliability is interesting; failing to know someone’s name is not horrible as often using their name can be avoided, but calling someone the wrong name, a false positive, is extremely bad. The price should be relatively low as this product is not something anyone needs, but more of a want. It should also not be apparent that you are using anything other than your memory to remember a person’s name.

One solution would be an app that ties in with Facebook, quizzing you on people’s names. Whenever you are going to a Facebook event, it uses the guest list to exercise your memory with pictures of the attendees. There are many advantages to this idea. It is completely safe and manufacturable. The cost is extremely low; potentially one dollar on the app store. However, there are a few downsides. The first is that it would only help remember people's names in the context of a Facebook event. The second is that it requires the premeditated action of quizzing yourself on people’s names, and even then you may not remember their name. The last is minor, but it may actually increase the rate of false positives by getting some names from the quiz stuck in your head. Overall, while this helps, it doesn’t solve the problem.

The next solution we came up with is an earpiece that recognized a person’s name via their voice. A microphone would record audio from a person introducing themselves and send the audio to a server where the person’s name and unique voice characteristics are extracted. The next time you hear that person talking, a small speaker in your ear would tell you their name. The pros of this idea are that it is fairly obscure. Having what would look like a hearing aid attached to your ear is not very noticeable. Even if it is noticed, its use is not apparent. The cons are that this product is more expensive. Another issue is that for you to get the person’s name, they have to be speaking with you already, meaning you can’t go strike up a conversation with that person’s name. The final issue is that it is very hard to uniquely identify a person based on audio; noise, multiple people speaking, and lack of defining audio characteristics would all lead to a higher rate of failure.

We proposed a realtime solution, the OmniView, which is a pair of glasses with a camera that can instantly display the name of the person you are currently at. Using an existing database of facename pairs such as a school registry, the glasses could take a picture of the person you are looking at and send the data to a server where the person’s unique facial structure is analyzed. The server would then return the name of the matching entry, showing the name of the person in front of you on an display in the corner of your vision. A new entry could also be dynamically created by taking a picture and sending that information to the server along with accompanying audio of their introduction or only sending the picture and adding their name to the server later. The pros are that facial recognition have the highest rate of success and the lowest rate of false positives. In addition, this could be used right before the interaction (looking across the room) to get the person’s name. The cons are that it is very noticeable you are wearing a device. It is also an expensive solution.

To remedy these issues, our idea in practice would be part of a larger product capable of acting as a camera, mobile notifications center, and augmented reality platform. This would all use the same hardware but the expanded feature set would bring far more value, justifying the high price. There is also the added bonus that it would be unclear what you were currently using this multifeatured device for, obscuring the fact you were using it to discover someone’s name. With these issues assuaged, this is the solution we are proposing to implement.

Implementation Issues

To achieve our highlevel goals for this project, we need to settle a number of lowlevel details. The image that is going to be captured will need to be high enough resolution for our facerecognition algorithm to work. The system needs to be fast enough such that there is no significant latency when the user sees a person and that person’s name pops up on the display. OmniView needs to be light enough and small enough so that it is not irritating to be worn by the user. The power draw of the device also needs to be low, since we are powering via a small battery attached to the headset.

Our primary mode of operation will involve taking an image from the camera at a rate of 1Hz and sending the image to the web server. The web server will be running our facial recognition algorithm. When the web server identifies the person in the received image, it will send the name of that person back to the microcontroller. The microcontroller will then drive that name onto the OLED display. In images with more than one person, the algorithm will identify the largest face in the image. If the server does not have a high enough confidence level in its identification of a person, it will send an error message indicating that no face was detected or the face did not match any existing entries. The OLED would continue to display the name of the last identified person until a timeout of 15 seconds, at which point the display would be cleared. In this mode, the facial recognition algorithm will be comparing images against a preloaded database of imagename pairs. The entire device will be turned on and off through a push button and this will be the default mode of operation.

Our secondary mode of operation will involve the use of a microphone and camera in tandem, and is initiated with a second push button. This button push will start a data capture which is 10 seconds of microphone data, and one picture taken 5 seconds after the push. This allows the button push to be done prior to the interaction, making it more subtle and preventing it from interrupting the interaction itself. The device will then send both the captured image and the ten seconds of the microphone signal to the web server. The web server will perform natural language processing to parse the spoken name from the microphone signal. If the web server does not have a high enough confidence level, it will reject the image and name. If there is no rejection, the web server will dynamically add the received image and processed name to the database of imagename pairs. The web server will then send a response to the device. If the web server failed to identify a face in the image or name from the audio, it will send the device an error message which will be displayed. If the webserver successfully added a nameimage pair to the database, it will send the name that the database was updated with. During an introduction, usually two names are said, the user’s and the target’s; however, the user’s name can be excluded because it is previously known. One issue is the exact spelling of the target’s name is impossible to determine from audio but that is acceptable and the server can be updated later if the exact spelling is different. For the duration of the secondary operation, primary operation will be paused.

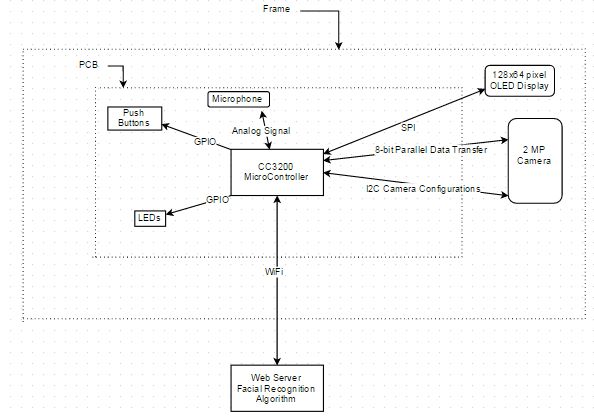
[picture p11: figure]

We have chosen to use an external server in our application. This server will perform the facial recognition algorithm and query the database of facename pairs. Using an external server and database allows us to keep the device worn on the face small and light. It also reduces the power draw of the PCB, which is being powered by a small battery on the headset. We will rely on opensource software for our facial recognition. To ensure feasibility, we have already selected our facial recognition algorithm, openBR, and successfully had 1.3 MP images identified against our sample database of facename pairs within 1 second.

The communication between the server and microcontroller will be conducted using WiFi. This is done for two reasons: it expands the maximum communication distance between the server and the device, and it allows for a high throughput of data. Images are fairly data intensive, and we want the latency between an image sent to the server and the corresponding text sent back to the microcontroller to be as short as possible. Another wireless protocol with high throughput and even higher range than WiFi is cellular. We chose not to proceed with a cellular protocol, because of the increased power draw that cellular would bring . In addition, the

1
intended use case for our device makes the increased range of cellular unnecessary. Using WiFi does introduce at least one added layer of complexity to the device: the registering of the device as a station in a network. Instead of creating a dedicated UI on the glasses for setting up connectivity, we would instead allow for OmniView to be connected to as an access point, and communicate with a user’s personal computer. Through this method, OmniView can be registered on the network through the use of a personal computer.

The features we are looking for in a microcontroller includes an interface for a high resolution camera, and support for a wireless protocol capable of streaming data. After some research, we determined the primary candidates to be the CC3200 and the STM32F479N. We chose to use TI’s CC3200 microcontroller. This microcontroller has a dedicated core that implements the WiFi WLAN and TCP/IP stacks. It also has an onchip 80 MHz Cortex M4 processor to perform other application logic and interface with peripherals. The microcontroller includes 2 UART modules, 1 SPI module, 1 I2C module, and an 8-bit parallel camera interface .

2
Freescale’s STM32F479N processor was given brief consideration for it’s MIPI controller . MIPI

3
is a camera interface used by many high resolution cameras. We decided on the TI CC3200 because it has built in support for a 2 megapixel camera and a core that handles the WiFi protocol. It is worth mentioning that TI has a surface mount antenna solution for the CC3200 development board. No one on the development team has experience with antenna design, so we intend to use the same surface mount antenna found on the CC3200 dev board. We believe this will result in the antenna being a nonfactor in our list of foreseeable difficulties with developing OmniView.

There are several advantages to having WiFi capability within the microcontroller rather than through an external module. The most important reason is the form factor. With WiFi being handled by the MCU, we don’t have to route a dedicated WiFi module. This would take up a lot of space in an application prioritizing low weight and size. Another important reason is that the vendor (Texas Instruments) has provided sample code for implementing WiFi on the microcontroller, which we can use as a reference in order to reduce development time. If we used a dedicated module, it is unlikely that we would be able to find sample code ported to our specific microcontroller.

We decided to use an Organic Light Emitting Diode (OLED) display over the popular Liquid Crystal Display (LCD). One reason for this decision is that OLED displays require less power than LCDs. OLED displays only draw power based on the section of the display that are nonblack. In contrast, LCDs filter a backlight that is always on, and must use power to make the screen dark. Another important factor is weight of the display; OLED displays are lighter

1
http://www.computerworld.com/article/2506011/wirelessnetworking/mobileuserspreferwifiovercellularfo rlowercostspeedreliability.html (http://www.computerworld.com/article/2506011/wireless-networking/mobile-users-prefer-wi-fi-over-cellular-for-lower-cost--speed--reliability.html)
2 http://www.ti.com/product/CC3200/datasheet/abstract#XXXX0015868
3 http://www.st.com/web/catalog/mmc/FM141/SC1169/SS1577/LN1876/PF260695 than LCDs. Communication between the display and the microcontroller will be done via a common serial protocol. OLED displays in our size range support I2C, SPI, or both. Since we only have 1 SPI / 1 I2C to work with, and the camera requires I2C, we can use the remaining SPI pins for the OLED display.

4

All of the electronic components will be contained on one PCB, with the exception of the OLED display and the camera. The OLED display will be mounted on the frame, and connected to the PCB. This decision was made for the sake of the user being able to read the words being driven onto the display. The camera will be mounted directly on the PCB in a 90 degree angle so that we can place the camera in an area on the frame (perpendicular to the temple) that will result in optimal image quality. The PCB will sit within the frame. The frame will be created using a 3D printer. We estimate the frame(we define frame as the 3D-printed glasses frame with the unpopulated PCB included), to weigh around 50g. We have discovered a kickstarter project for 3D-printed glasses frames that claims a weight of 11g . They use nylon as their plastic of

5
choice. Due to the constraints of the 3D-printers at the university, we intend to use ABS plastic. ABS is slightly less dense than nylon . Even though we’re using a lighter material than the other

6
frame developers, we expect our inexperience with 3D-printing CAD tools will result in a frame that is 3-4 times as heavy as the 11g nylon frame.

The size and weight of the entire device are two very important application parameters. If either value is too high, the headmounted device is unusable. We will need to ensure that the weight of OmniView is not uncomfortable to the user. In addition, we need to make sure that the size is reasonable. Size also affects whether or not OmniView will be socially acceptable. We recognize that for a prototype, the device will probably not have the necessary form factor to be socially acceptable. Even google glass has problems with social acceptability, and that device was developed with a much larger budget and longer time frame than our device.

Given our peripheral choices, we estimate that our electronic devices will have a combined weight of 23 grams. Our chosen battery weighs 17 grams. Our total estimate for the weight of our device comes out to be 90g. We researched a similar device Google Glass and found that it weighs 43 grams. Given the weight of Google Glass, which we consider to be the minimum for complex electrical devices worn on the face, we consider the estimated weight of our device to be acceptable.

The glasses will have dimensions that are slightly larger than Google Glass. We plan to fit all the electronics on the right side of the frame, and hence, we expect a thicker and heavier temple on the frame. The temple is going to be 20mm wide (top to bottom of the temple piece) and approximately 10mm thick (left to right of temple piece). We wanted the glasses to be symmetric on both sides of the frame, but still not compromise on weight. Therefore, we decided

4 http://electronics.howstuffworks.com/oled5.htm
5 https://www.indiegogo.com/projects/monoaneyewear-3dprintedtofityourface#/ (https://www.indiegogo.com/projects/mono-an-eyewear-3d-printed-to-fit-your-face#/)
6 http://www.dotmar.co.nz/density.html to design the left temple piece identical to the right, but have it be hollow to reduce the overall weight.

We have also considered nontechnical issues that might arise after the product has been built and used. One of them is the privacy laws pertaining to the recording and taking of photographs of people in public. It is generally legal in the United States to take photographs or record videos of objects and people when you are within public property. The right to do so in a private property is ultimately decided by the property owner. However in practice, this law does

7
not inhibit smartphones users and we do not see it as an issue for our device either. There are currently many different approaches and proposed solutions regarding privacy concerns, but the laws have not caught up with wearable technology yet. There is no law that recording devices must have a light on or make a noise when taking a picture. Nevertheless, we will continue to develop the product with these laws in mind.

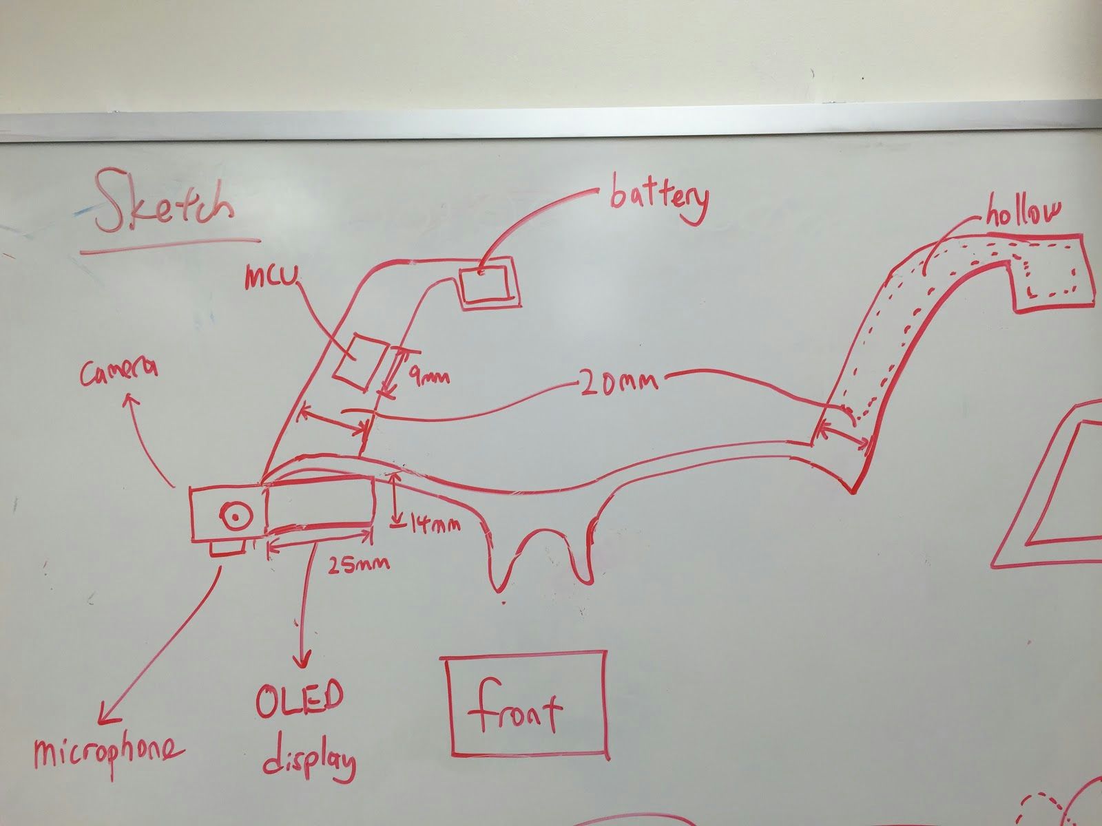
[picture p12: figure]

7 http://www.krages.com/ThePhotographersRight.pdf

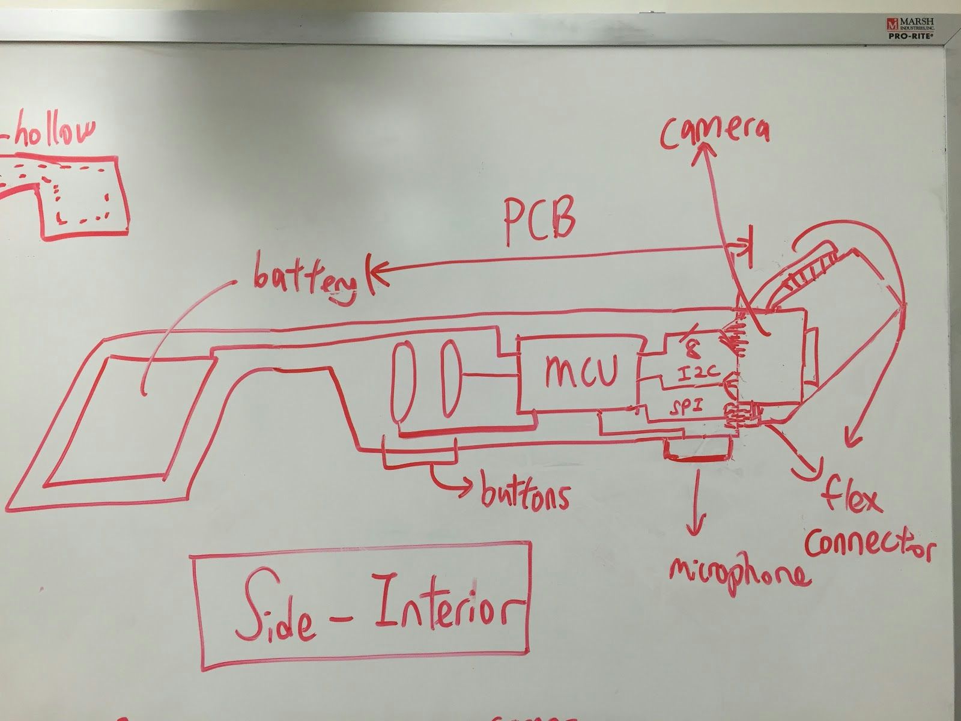
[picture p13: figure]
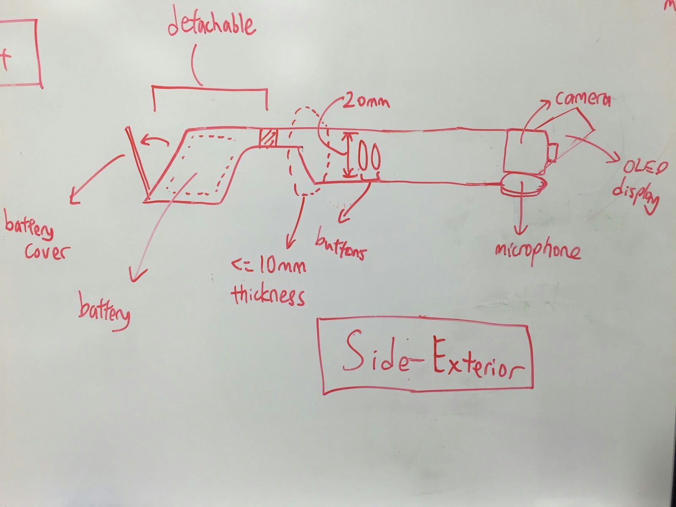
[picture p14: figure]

Task | Start Date | Duration
| | (days) | End Date
Decide on the microprocessor families and components models | Sept. 21 | 11 | Oct. 02
Decide on reasonable face recognition libraries | 21 | 11 | 02
Work on the final proposal and order development boards. | 28 | 06 | 04
Order components | 28 | 06 | 04
Wifi should at least be able to send/receive something (dev board) | Oct. 04 | 07 | 11
Board and schematic design | 04 | 16 | 30
Implement OLED interface and user interface (dev board) | 04 | 42 | Nov. 15
Implement Face Recognition Algorithms (dev board) | 04 | 42 | 15
Order PCB + shipping time | 30 | 16 | 15
3D print the frame of the glasses | Nov. 15 | 02 | 17
Software development on face recognition feature with PCB | 17 | 08 | 25
Fix remaining bugs on Wifi and OLED with PCB (if any) | 17 | 08 | 25
Implement stretch goals if possible Microphone | 18 | 15 | Dec. 03
Fix minor bugs, enclosures and final writeups | 25 | 15 | 10

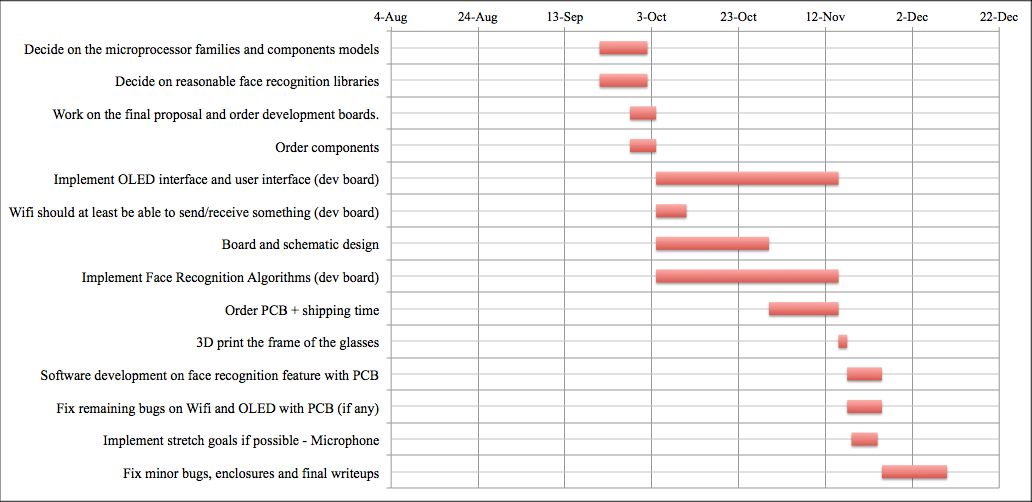
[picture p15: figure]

The main bottlenecks of this project are going to be the development of the PCB and 3D printing the frame of the glasses.

Since the PCB we are dealing with is going to be small, we might need to be careful when we solder on it. That’s why we allocated a lot more days for PCB ordering and shipping time, as well as testing it when it arrives before mid November. We generally expect it to arrive in the first week of November, and if anything goes wrong, we can reorder them again and still make it in time for our deadline.

Another thing that could go wrong is with the components and dev boards are not shipped in time for us to begin the project. However, we have already selected all the components we will use and ordered them. In addition, a few of us have these exact components at home, so we will not be idle while waiting for the parts to be shipped.

We will need a 3D printer to create the frame of the glasses. The 3D printers in the Dude are a little bit difficult to work with, and we will talk to people in the mechanics lab who have access to more advanced 3D printers. We have allocated time to get this done after we receive our PCB just in case anything is wrong with the dimensions of the PCB can be accounted for by changing the enclosure around it. For milestone 1, the prototype will be capable of displaying meaningful text on the OLED display. Basic Wi-Fi module will be able to send/receive data from server. We hope that PCB schematic design will be done. The image recognition algorithm should already be implemented and able to show meaningful information. For milestone 2, the PCB will have been ordered. The OLED display and Wi-Fi software will be finished with only minor bugs left, and we will have decided on whether we want to implement functionalities related to the microphone. In addition, the frame of glasses will have been 3D printed.

Design Expo & Presentation

By the time of the design expo, we will have a complete PCB for the device. We will have also created a 3D-printed set of glasses to mount this PCB onto. We will demonstrate OmniView by allowing people to wear the glasses, then identify people in our group who will all be registered in the facename database. If we have completed the stretch goal of dynamic addition to the database, we will also use this feature and show them the glasses now recognize them and display their name.

In the auditoriumstyle demonstration to the rest of the class, we will use a member of the audience to repeat the above demo, but also have the server display the name associated with received images to a terminal and project that on the screen behind us. The only need we have for the demonstration is that the room the demonstration is being done in is welllit, so that the images being captured are of high quality.

Since our project uses WiFi on University grounds, we will also need make sure that our device is made known to the university. We intend to have Omniview function as an access point for the purposes of the demonstration, so we don’t have to deal with the added complexity of setting it up Omnview a station and connecting to a university access point.

Budget & Materials

The components needed to implement this project are listed in the table below. We focused on choosing components that would minimize our weight, size, and power draw.

Components | Description | Quantit y | Cost/item | Total Cost
Micron MT9D111 Camera | ● Supply Voltage 2.5 V ~ 3.1 V ● 2 Megapixels ● Size:8mm x 6 mm ● Weight: 5g ● Power: ○ 348mW at 15 fps, full resolution ○ ≈94mA | 2 | $10.19 | $20.38
Univision OLED display | ● Supply Voltage 3.3 V ● Monochrome ● 128*64 pixels ● Size: 25mm x 14mm ● Weight: 8.5g ● Power: ○ sleep mode 5uA ○ max 28.9mA | 2 | $14.95 | $29.9
Microphone | ● Supply Voltage 2.7~5.5 V ● SNR 64 dB ● Size: 9.7mm x 4.5mm ● Weight: 0.8g ● Power: ○ sleep mode 1uA ○ max 6mA | 1 | $7.95 | $7.95
Texas Instruments CC3200 MCU with Wifi Network | ● ARM Cortex M4 Core 80 MHz ● Built in Wi-Fi 802.11 b/g/n ● 8-bit parallel camera interface ● 27 GPIO pins ● Size: 9mm x 9mm ● Weight: 2.5g ● Low Power Modes | 5 | $18.92 | $94.60

| ○ Hibernate: 4 µA ○ LPDS: 250 µA
PCB | ● Weight: PCB + Misc. Parts: ≈ 50g | 5 | $20.85 | $104.25
SimpleLink Wi-Fi CC3200 Dev Board | ● Development board for MCU | 2 | $29.58 | $59.16
Camera Booster Pack | ● Camera “shield” for CC3200 | 2 | 38.06 | $76.12
Lithium-polymer charger | ● Charges Lipo Battery | 2 | $7.95 | $15.8
Lithium-polymer battery | ● Output: 680mAh ● 3.7 VDC. ● Size:40 x 25 x 8.5mm ● Weight: 17g | 5 | $16.99 | $16.99
Misc. Parts | ● LED, Buttons, 3D printing materials and other passive components | | | $200.00
Shipping | | | | $200.00
Total | | | | $822.15

Camera:
http://www.newegg.com/Product/Product.aspx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 (http://www.newegg.com/Product/Product.aspx?Item=9SIA5W02EF6650&nm_mc=KNC-GoogleMKP-PC&gclsrc=aw.ds)

Univision OLED Display:
http://www.adafruit.com/products/326

Texas Instruments CC3200 MCU: http://www.digikey.com/productsearch/en?mpart=CC3200R1M2RGC&v=296 (http://www.digikey.com/product-search/en?mpart=CC3200R1M2RGC&v=296)

Texas Instruments CC3200 Dev Board: http://www.ti.com/tool/CC3200-LAUNCHXL?keyMatch=cc3200%20launchpad&tisearch=Search -EN-Everything#buy (http://www.ti.com/tool/CC3200-LAUNCHXL?keyMatch=cc3200%20launchpad&tisearch=Search-EN-Everything#buy)

Texas Instruments CC3200 Camera Booster Pack http://www.aliexpress.com/item/CC3200-Camerabooster/32276520437.html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 (http://www.aliexpress.com/item/CC3200-Camera-booster/32276520437.html?src=google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)

Microphone:
http://www.adafruit.com/products/1713

Lihiumion polymer Battery: http://www.miniinthebox.com/symax5cx5c-1-explorerspartsx5c-11-3-7v-500mahupdate-3-7v-680mahlipobattery-3-in-1-cablelinex-5pcs_p2041286. (http://www.miniinthebox.com/syma-x5c-x5c-1-explorers-parts-x5c-11-3-7v-500mah-update-3-7v-680mah-lipo-battery-3-in-1-cable-line-x-5pcs_p2041286.html)

3-D printing plastic:
http://www.makershed.com/products/1-75mmabs-1kgspooledfilament?gclid=Cj0KEQjwb2wB RDcrKerwe-S5c4BEiQABprW-IJFh5Xj-NJSy5-yB43XXVX5OqK1UEVK9iAmf0rJn1MaAnZA8P8 HAQ (http://www.makershed.com/products/1-75mm-abs-1kg-spooled-filament)

As mentioned previously, the target weight of OmniView is less than 100g and the target power consumption is less than 450maH. The device should be small enough to be comfortably worn. All the components listed in the table above are selected based on satisfying these criteria. The major components that will be included in the final product are TI’s CC3200 microprocessor, Micron’s MT9D111 camera, a 128x64 pixel OLED display, the microphone, battery, PCB, and 3D printed frame.

TI CC3200 Microprocessor + Wi-Fi

As mentioned in the Implementation Details section, the Texas Instruments CC3200 MCU comes with a Wi-Fi network processor. OmniView will be transmitting 2 MP images to the server at a frequency of 1 Hz and returning the facial recognition result back to the system. With 802.11 b/g/n specification, and using the TCP networking protocol, the processor is capable of transmitting up to 13 Mbps. This transmission rate is sufficient for our application. The low power consumption of the CC3200 MCU makes it more attractive, which takes about 350mA in the worst case.

Micron MT9D11 Camera

A high quality camera is required for this application, since the captured image will be used for facial recognition. Using pictures taken from a 1.3 megapixel front camera on a Nexus 5, the facial recognition algorithm successfully identified the members of the development team from about 10 feet away. Given this experiment, we believe a reasonable target resolution is 1.3 megapixels or higher. Low power consumption is also an essential criteria for our camera module.

We researched a couple of camera modules such as the OV5460, OV2722, OV3660, Micron MT9M11 and MT9D11 that have the potential to support the TI CC3200 MCU and meet our constraints. The OV Cameras have superior performance (above 2 megapixels with lower current drain), however, they only support either serial interface (CSI) or 10-bit camera parallel interface (CPI) data output. This is problematic, as our MCU has an 8 bit CPI data input. Of the cameras we evaluated, only the Micron MT9M11and MT9D11 use an 8 bit CPI data input. We found that the MT9D has 2 megapixel resolution while the MT9M has only 1.3 megapixels. Even though the power consumption for the D version (≈94mA) is about twice as much as the M (≈45.9mA), we believe the additional resolution of the MT9D will lead to increased success for the facial recognition algorithm, and have decided to use the Micron MT9D11 for this project. Another advantage of the D version is that CC3200 MCU happens to have existing MT9D11 drivers, which means using the MT9D11 will save us a lot of development time.

Univision OLED display

We need a small display that can exhibit a decent amount of information (high pixel density), as well as being power efficient when sleep mode is activated. We evaluated several OLED displays and decided that the Adafruit 128x64 OLED display is well suited for our application. The screen also ships with flexible connectors, which we will incorporate into our 3D printed casing. The Sparkfun display was a little too expensive given our budget.

PCB

The number of PCBs required is a rough estimate, and depends mainly on the quantity the manufacturer can supply. However, having a couple backup PCBs will give us more space when dealing with unpredictable failures.

Battery

We currently propose to use a 680mAH battery for our face recognition glasses. Since the battery is one of the heaviest components that we are going to mount on the glasses, we need to keep track of the battery size and weight without compromising the usability and practicality of the glasses. We mapped out our power draw of all the electronic components, and concluded a worst case current draw of 456.05mA.

current(battery)
= current(camera) + current(display) + current(microphone) + current(wifi module + processor) = 94.05mA + 6mA + 6mA + 350mA
= 456.05mA

This calculation assumes all our components are operating at the same time, and indicates that we will have at least 1.5 hours of battery life. We are not going to use all our components all at once, so we can expect to have a longer battery life than this.

Google Glass has a 570mAH Lithiumpolymer battery which fits in the right end of glasses. We plan to do a similar setup for the 680mAH battery, which has a mass of 9g.

Conclusion

Overall, we believe that remembering names and faces is a real challenge that exists in our world. Our project simplifies the process and gives you a visual aid to help with that problem. The project is realistically accomplishable and our main risks remain in getting everything accomplished in our timeframe, with the device being small, light, and fast. If the software and hardware are not able to perform at a reasonably high level, it will affect the performance of our whole project by attaching a significant lag to the retrieval of a person’s name. Despite this potential issue, we as a group are very dedicated and passionate about getting the project working, and are prepared to invest significant hours to make this happen.

Appendix A

Design Criteria | Importance | Will/Expect/Stretch
Facial recognition correctly determines new/old faces > 80% | Fundamental | Will
OLED displays name and info quickly enough such that user will not have to wait | Fundamental | Expect
Battery power > 1 hour | Important | Will
User has simple/efficient control of the glasses | Important | Will
Weight should not exceed such a limit that it will cause pain or discomfort to the user | Important | Expect
Software & Microphone are able to capture and person’s name | Optional | Stretch
Flexible PCB | Optional | Stretch

Appendix B

Milestone 1:
Prototype is capable of displaying meaningful text on the OLED display.
Basic Wi-Fi module is able to send/receive data from server.
PCB schematic design should be done.
The image recognition algorithm should already be implemented and able to show meaningful information.

Milestone 2:
PCB should have been ordered by now.
The OLED display and Wi-Fi software should be finished with only minor bugs left. Have decided on whether we want to implement functionalities related to the microphone.
Frame of glasses should be 3D printed by now.

Appendix C

class Camera {
public:
Camera(CameraMode mode);
void takePicture(int* buf, int& bufSize); void sleep();
void wakeUp();
private:
void initCameraMode(CameraMode mode);
enum CameraMode {RGB565, RGB555, RGB444, JPEG422, JPEG420, Raw10Bit};
uint8_t parallel_port; // 8-bit camera parallel port.
};

class Display {
public:
Display(DisplayMode mode);
void writeLine(int line, string message); void clearLine(int line);
void clearScreen();
void sleep();
void wakeUp();
private:
void initDisplayMode(DisplayMode mode); enum DisplayMode {SPI, I2C};
};

class Microphone {
public:
Microphone();
void record(int seconds, int* micBuf, int& bufSize); void sleep();
void wakeUp();

private:
void initMicrophone();
void startRecording(int* micBuf, int& bufSize); void endRecording();
};

class WifiModule {
public:

WifiModule();
void sendPicture(int* picBuf, int bufSize); void sendAudio(int *micBuf, int bufSize); string getResponse();
void sleep();
void wakeUp();
private:
void initWifiModule();
void sendTCP(int* buf, int bufSize, int ipAddr); void receiveTCP(int* buf, int bufSize, int ipAddr); };

class MCU {
public:
MCU();
void sleep();
void wakeUp();
private:
void boot();
};

class FaceRecognitionSoftware { public:
void receiveRequest(RequestType& type, int* buf, int& bufSize);
// returns result string. ex: “Garrison” success, “No Face Found” failure string comparePicture(int* picBuf, int bufSize);
string addToDatabase(int* picBuf, int bufSize, string name);
string addToDatabase(int* picBuf, int bufSize0, int* micBuf, int bufSize1); void sendResponse(string response);
private:
enum RequestType {compareFace, addFace};
void openBrInit();
void openBrAnalyze(string imgPath);
void openBrCompare(string imgPath, string galleryPath);
void addFaceNamePair(string imgPath, string name, string galleryPath); void sendTCP(int* buf, int bufSize, int ipAddr);
void receiveTCP(int* buf, int bufSize, int ipAddr);
};

Appendix D

Each person in the group has agreed to the following:

- 25 hours/week are expected of each person
- The group is free to meet on Tuesdays, Wednesdays, Saturday afternoons, and Sundays
- The team plans on getting most of its work done as early as possible.
- The team will work together as much as possible and individually only when necessary (or away).
- We all agree to meet every Sunday to work together, and this will also us to do weekly progress checks.
- Tasks responsible for:
- Mechanical: Tzu-Fei
- PCB & Soldering: John, Tzu-Fei
- Programming: Garrison, Loren, Bobby
- Scheduling Meetings: Garrison
- Minutes: John, Bobby
- Requirement Gathering: Garrison
- Known Conflicts/Missed Time:
- Interviews: Everyone
- Thanksgiving: Garrison, John
- Badminton Tournaments: Loren
- Team meetings will be held in lab.
____________________________ | ____________________________
____________________________ | ____________________________

____________________________

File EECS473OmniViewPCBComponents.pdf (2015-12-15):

| | SPEC | Part Number | Quantity Needed per board | Quantity Needed for 4 boards | Ordered | Links | Links
Soldering:
| Solder paste | | | 1 | 4 | N
| Stencil | | | 2 | 8
| PCB board | | | 1 | 4

Passives:
| Capacitors | 1pF | "0402" | 1 | 4 | Y | http://www.digikey.com/product-detail/en/UVK105CH010BW-F/587-1007-1-ND/930784
0.1uF | "0603" | 3 | 12 | Y | http://www.digikey.com/product-detail/en/CC0603KRX7R7BB104/311-1088-1-ND/302998
0.01uF | "0603" | 1 | 4 | Y | http://www.digikey.com/scripts/DkSearch/dksus.dll?Detail&itemSeq=183337511&uq=635823721291238010
2.2uF | "0603" | 3 | 12 | Y | http://www.digikey.com/product-detail/en/JMK107BJ225KA-T/587-1254-1-ND/931031
10uF | "0603" | 2 | 8 | Y | http://www.digikey.com/product-detail/en/CL10A106MQ8NNNC/1276-1119-1-ND/3889205
15pF | "0603" | | 4 | Y | http://www.digikey.com/product-detail/en/06035A150JAT2A/478-1165-1-ND/564197
0.47uF | "0603" | 1 | 4 | Y | http://www.digikey.com/product-detail/en/C1608X7R1C474K080AC/445-5192-1-ND/2093807
Resistors | 100k | "0603" | 3 | 12 | Y | http://www.digikey.com/scripts/DkSearch/dksus.dll?Detail&itemSeq=183337968&uq=635823728915102478
| 2.7k | "0603" | 1 | 4 | Y | http://www.digikey.com/product-detail/en/RC0603JR-072K7L/311-2.7KGRCT-ND/729682
| 270 | "0603" | 2 | 8 | Y | http://www.digikey.com/product-detail/en/RC0603FR-07270RL/311-270HRCT-ND/730050
| 10k | "0603" | 4 | 16 | Y | http://www.digikey.com/product-detail/en/RC0603FR-0710KL/311-10.0KHRCT-ND/729827
| 1k | "0603" | 3 | 12 | Y | http://www.digikey.com/product-detail/en/RC0603FR-071KL/311-1.00KHRCT-ND/729790
| 33 | "0603" | 2 | 8 | Y | http://www.digikey.com/product-detail/en/RC0603FR-0733RL/311-33.0HRCT-ND/730105
| 3.3k | "0603" | 2 | 8 | Y | http://www.digikey.com/product-detail/en/RC0603FR-073K3L/311-3.30KHRCT-ND/730073
| 150k | "0603" | 1 | 4 | Y | http://www.digikey.com/product-detail/en/RC0603FR-07150KL/311-150KHRCT-ND/729906
| 2.2k | "0603" | 1 | 4 | Y | http://www.digikey.com/product-detail/en/RC0603FR-072K2L/311-2.20KHRCT-ND/729963
30.1k | "0805" | 1 | 4 | Y | http://www.digikey.com/scripts/DkSearch/dksus.dll?Detail&itemSeq=183338573&uq=635823737456730462
52.3k | "0805" | 1 | 4 | Y | http://www.digikey.com/product-detail/en/RC0805FR-0752K3L/311-52.3KCRCT-ND/730968
| 0 | "0402" | 2 | 8 | Y | http://www.digikey.com/product-detail/en/MCS04020Z0000ZE000/MCS0402-0.0-ZZCT-ND/2607873
Inductor | 3.6nH | "0402" | 1 | 4 | Y | http://www.digikey.com/product-detail/en/LQG15HN3N6S02D/490-6562-1-ND/3845759
Switch | | EVQ11A04M | 1 | 4 | Y | http://www.digikey.com/scripts/DkSearch/dksus.dll?Detail&itemSeq=183340035&uq=635823758052568806
LEDs | Blue 3.3V | "0603" | 8 | 32 | Y
| Battery | >650mAh <20g <8500 mm3 | 2 | 8 | Y | https://www.sparkfun.com/products/341 | https://www.tindie.com/products/Rayshobby/700mah-lipo-battery-37v/
| Battery connector PH | | | 1 | 4 | Y | https://www.adafruit.com/products/1769 | https://www.sparkfun.com/products/9749
| Battery Charger | | | 3 | | Y | https://www.sparkfun.com/products/10401
Modules:
| microcontroller | | CC3200MOD | 1 | 4 | 2
| Microphone ELECTRET | | CMA-4544PF-W | 1 | 4 | Y | http://www.digikey.com/scripts/DkSearch/dksus.dll?Detail&itemSeq=183340432&uq=635823763184544996
| Antenna | | AH316M245001-T | 1 | 4 | Y | http://www.digikey.com/product-detail/en/AH316M245001-T/587-2200-1-ND/2002898
| ferrite beads | | 0805 - check adafruit mic breakout board for specific info
| uFL connector | | | | | Y
| LDO 3.3V | | TPS73733DRVR | 1 | 4 | Y
| | | TPS73733DCQ | 1 | 4 | Y
| | | TPS72501KTTT | 1 | 4 | Y
| | | TPS72501DT | 1 | 4 | Y
LDO 2.8V | TPS79328DBVRG4 | 1 | 4
JC: LDO 1.8V | TPS79318DBVR
Dual-Bit Dual-Supply Bus Transceiver | SN74LVC2T45DCUT | 1 | 4
NOTE: We can get TI stuff for free. Just request sample for now.
Microphone Amplifier | MAX9814 | 1 | 4 | Y | http://www.digikey.com/scripts/DkSearch/dksus.dll?Detail&itemSeq=183340290&uq=635823761726671852

Connectors:
| Pin Head | 1x2 | 2 | 8 | lab
| | 1x4 | 1 | 4 | lab
| | 1x7 | 1 | 4 | lab
| Ribbon Cable | 16 pins | 1 | 4 | JC:should have some in lab, wouldn't hurt to order a few

http://www.amazon.com/Superbright-0603-Emitting-Diode-2-85-3-0V/dp/B00NWFVXSS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

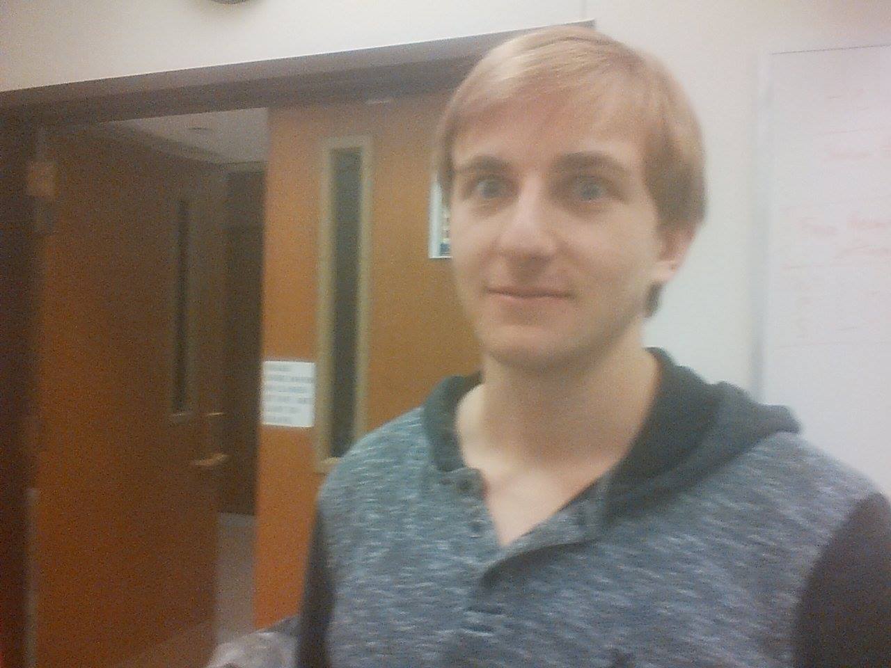
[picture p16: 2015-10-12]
face_software/training/John Connally/johnNoGlasses.jpg

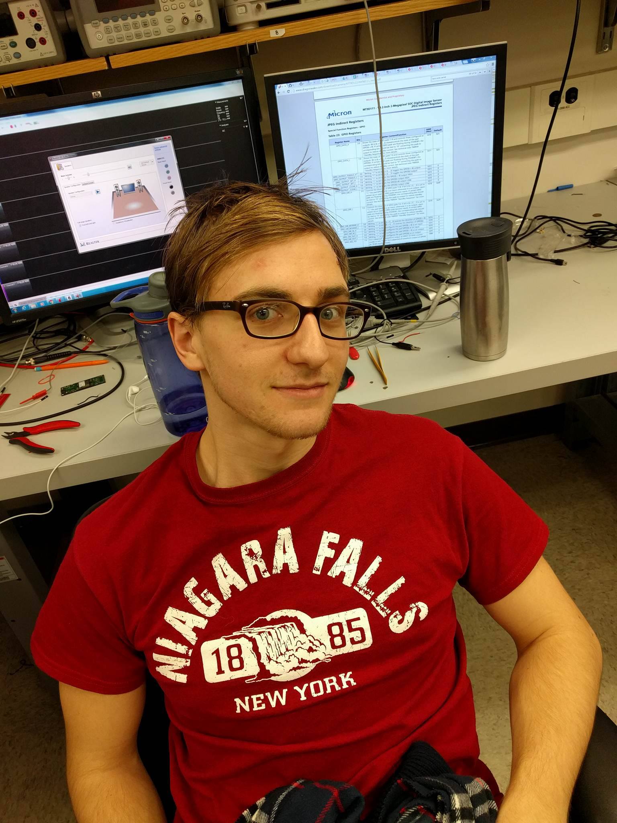
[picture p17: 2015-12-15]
face_software/training/John Connally/john2.jpg

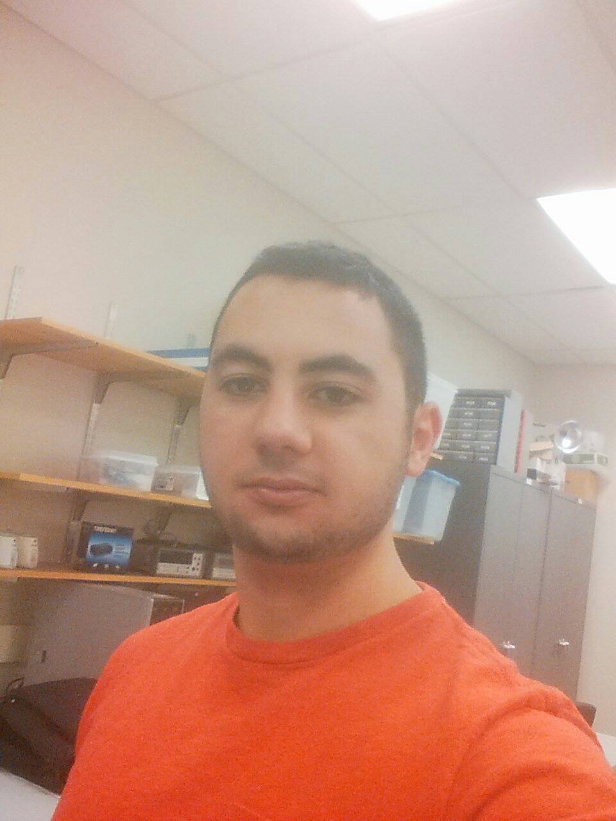
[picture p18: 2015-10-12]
face_software/training/Garrison Bellack/garrison0.jpg

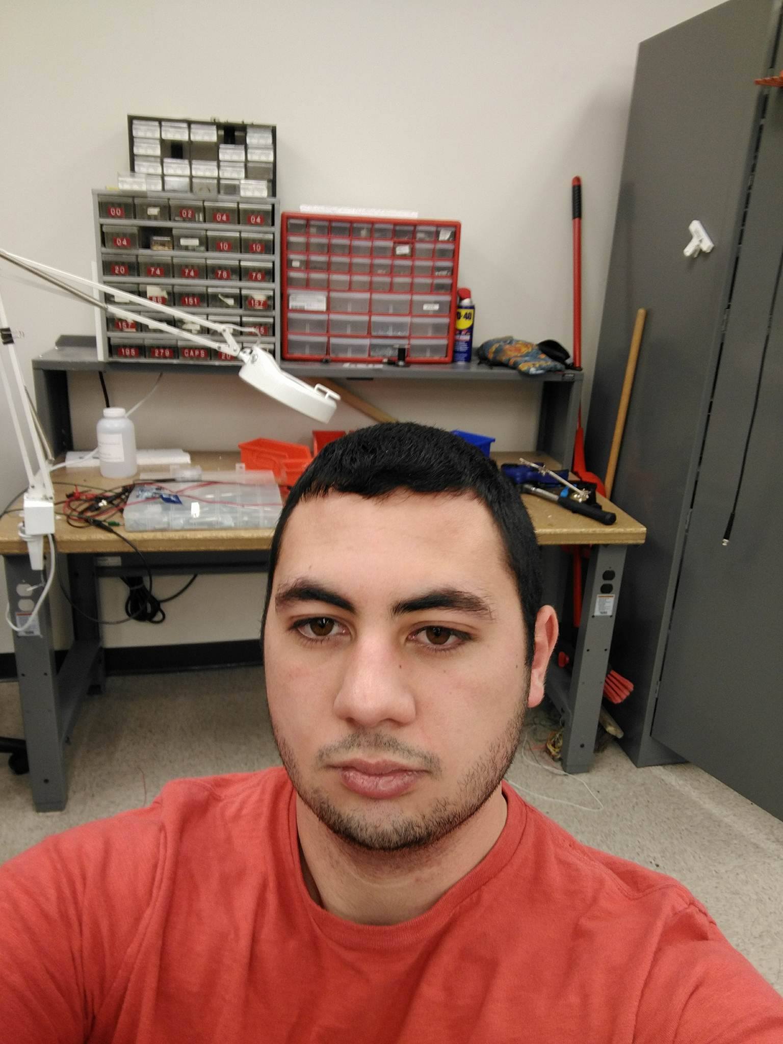
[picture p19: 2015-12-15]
face_software/training/Garrison Bellack/garrison4.jpg

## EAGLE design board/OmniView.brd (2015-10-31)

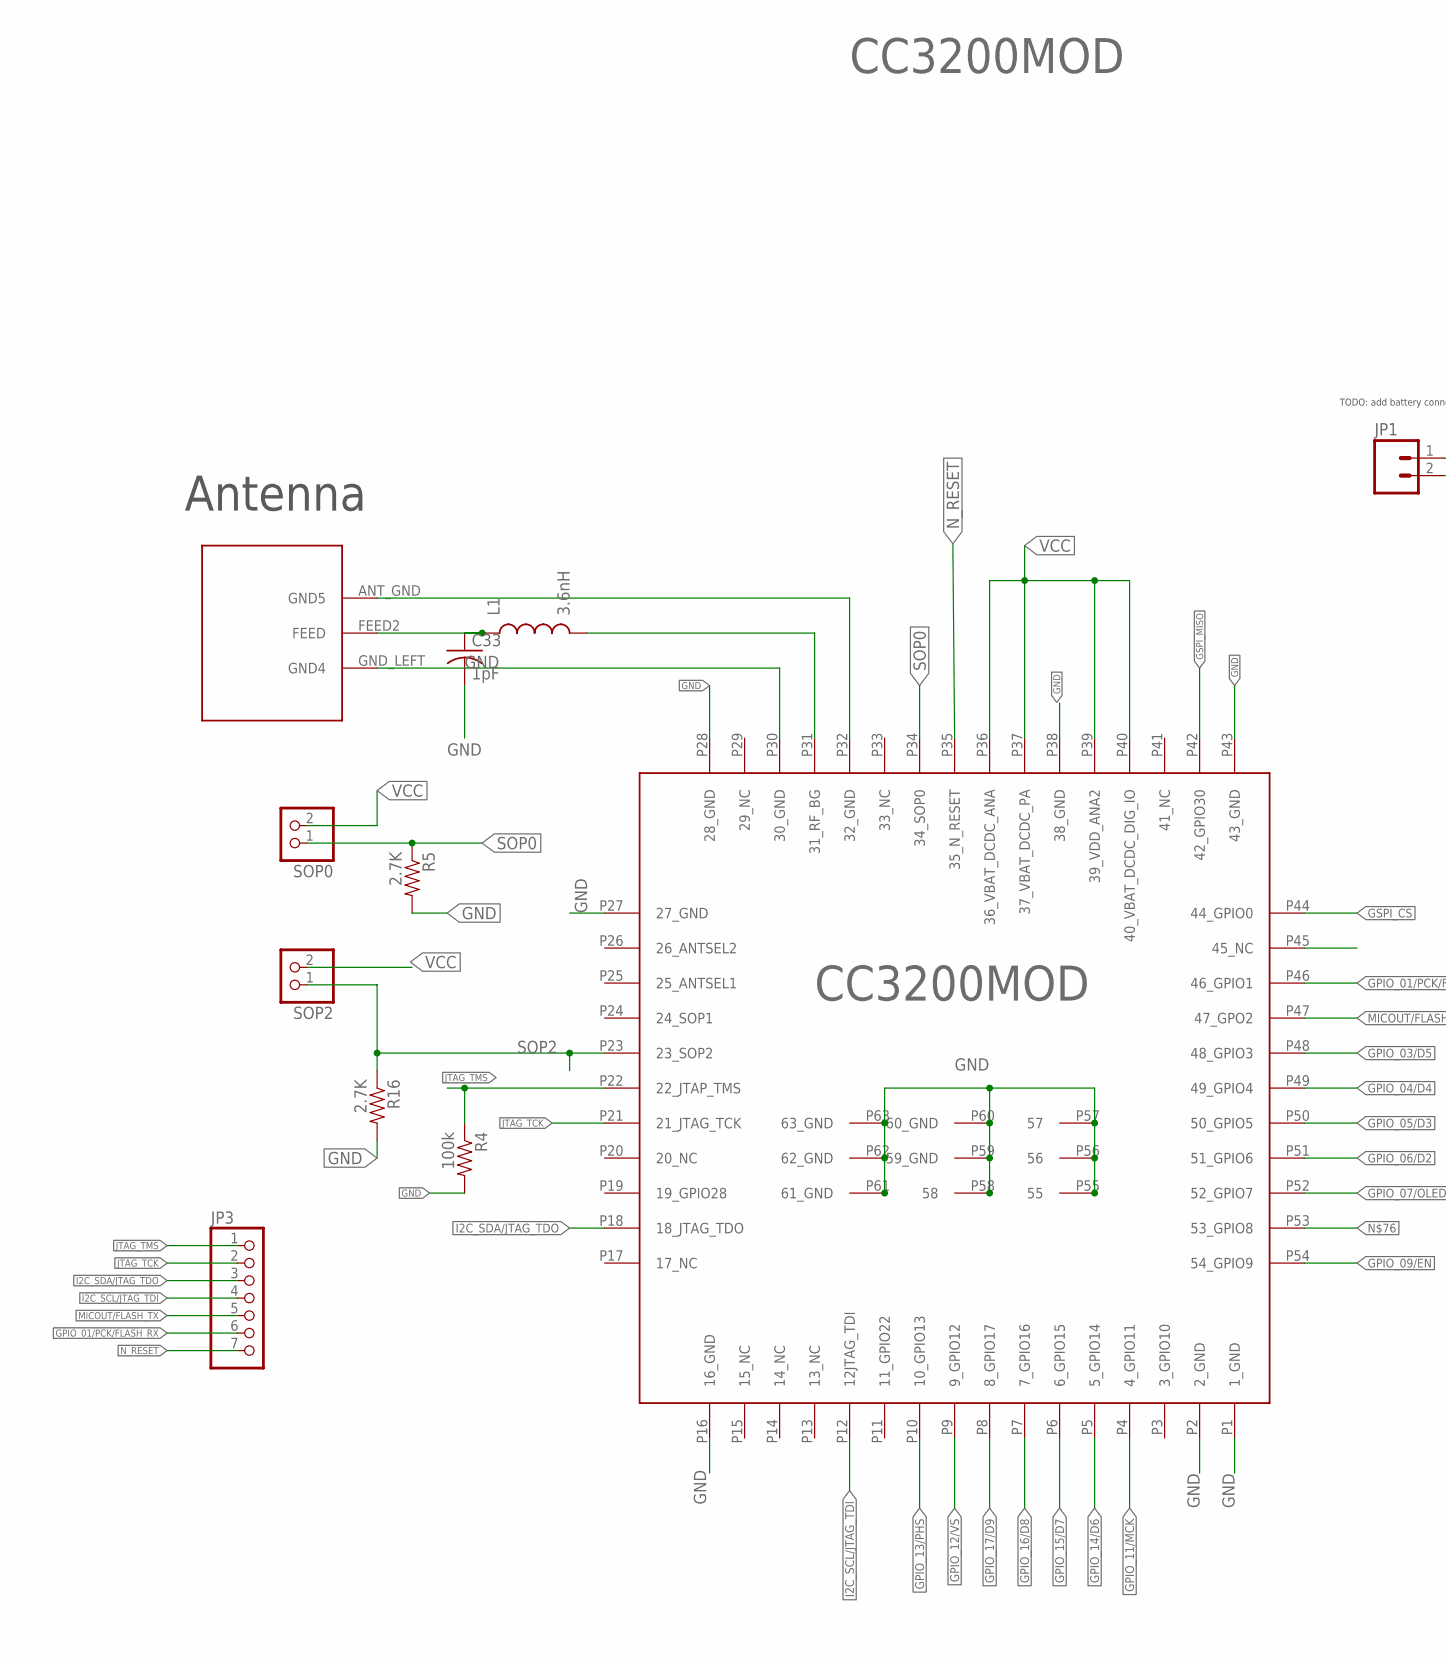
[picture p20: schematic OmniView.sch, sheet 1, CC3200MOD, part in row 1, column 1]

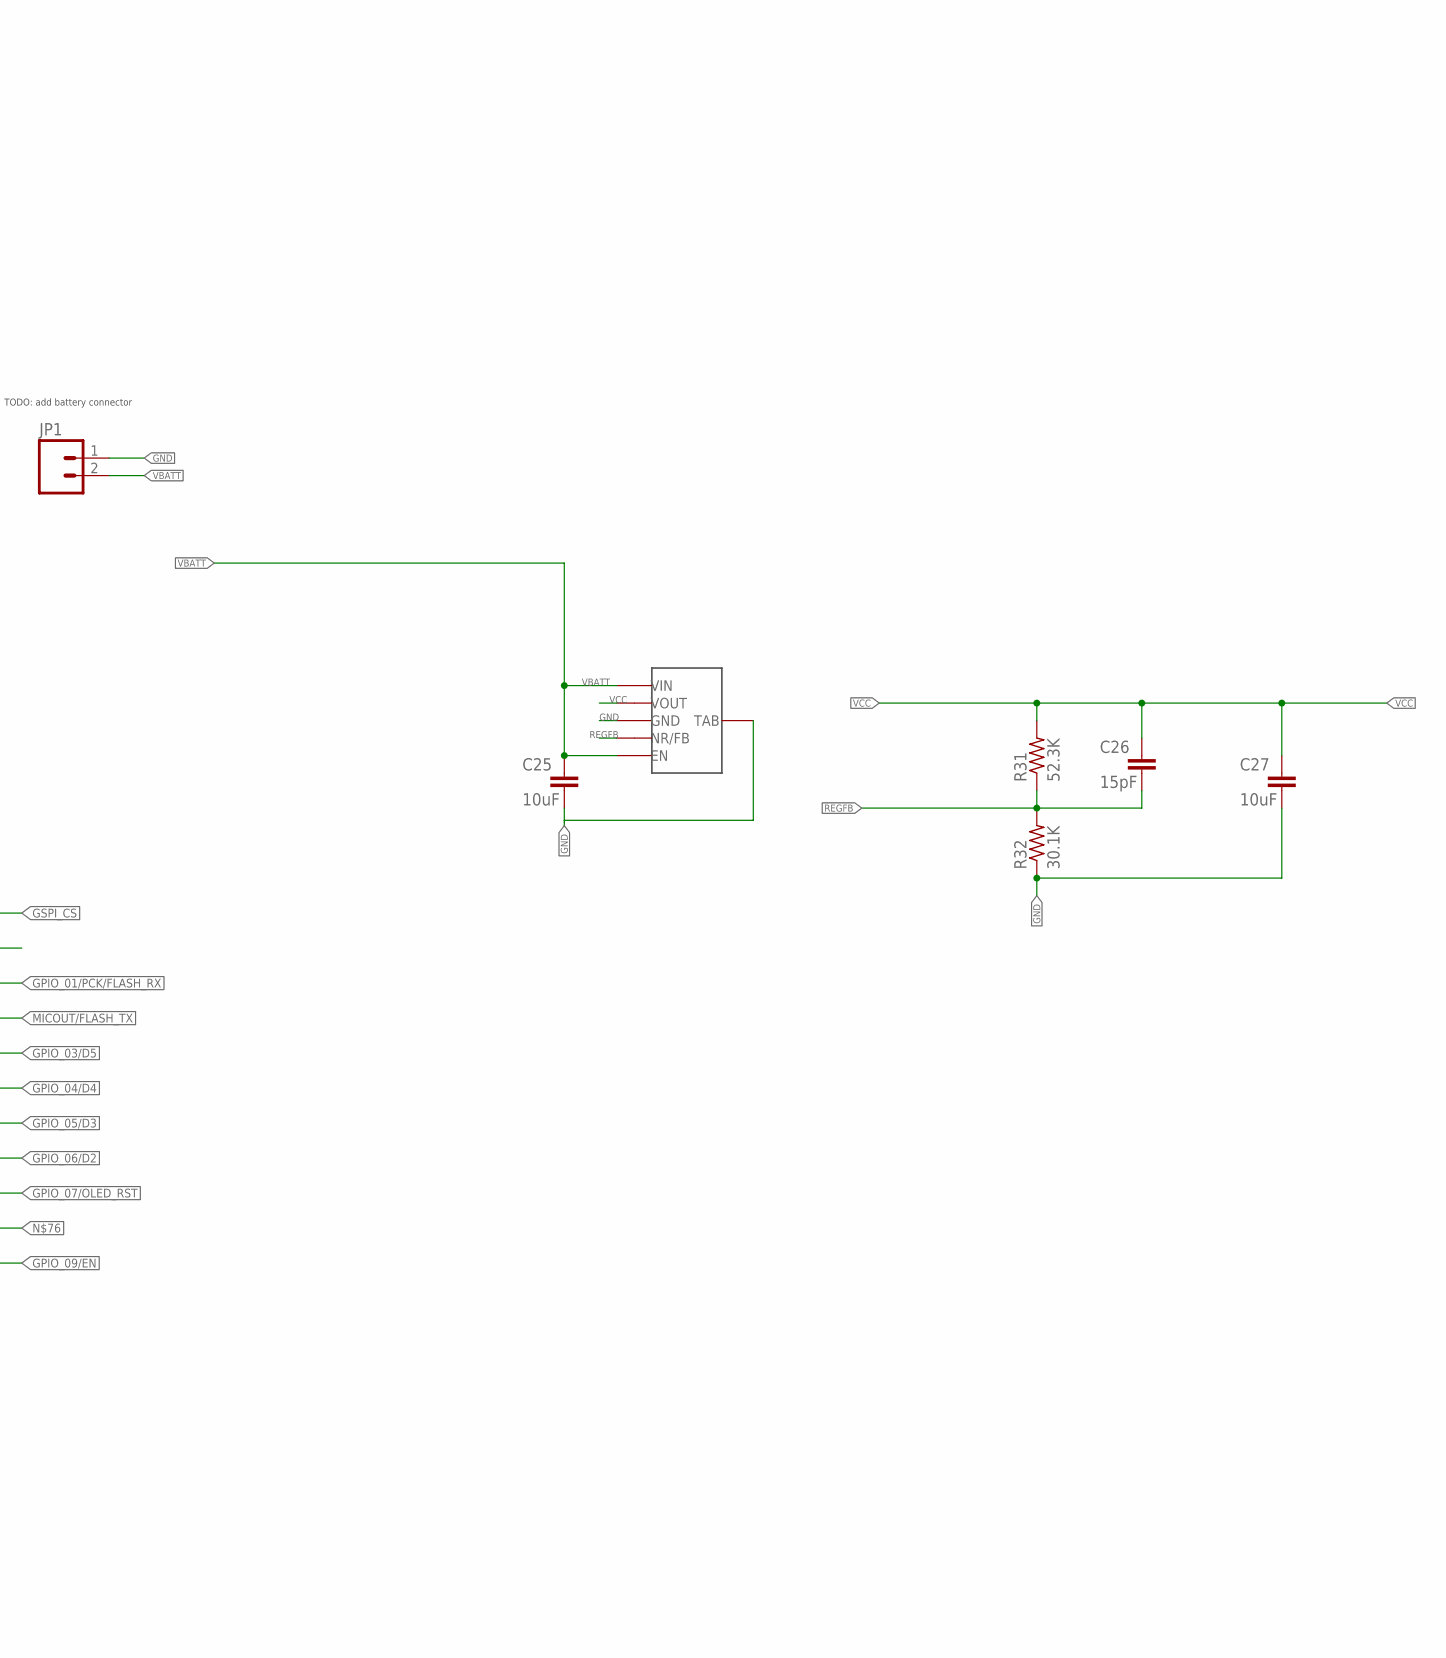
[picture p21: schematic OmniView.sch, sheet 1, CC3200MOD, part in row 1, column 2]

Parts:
ANT_PAD: ANT
C25, C27: 10uF; C0603
C26: 15pF; C0603
C33: 1pF; C0402
CC3200MOD: CC3200; CC3200MOD
JP1: M02-JST-2MM-SMT; JST-2-SMD
JP3: PINHD-1X7; 1X07
L1: 3.6nH; C0402
R4: 100k; 0603-RES
R5, R16: 2.7K; 0603-RES
R31: 52.3K; R0805
R32: 30.1K; R0805
SOP0, SOP2: PINHD-1X2; 1X02
U$30: TPS737_DCQ

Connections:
GND: ANT_PAD.ANT_GND (GND5), ANT_PAD.GND_LEFT (GND4), C25.2, C27.2, C33.2, CC3200MOD.P1 (1_GND), CC3200MOD.P2 (2_GND), CC3200MOD.P16 (16_GND), CC3200MOD.P27 (27_GND), CC3200MOD.P28 (28_GND), CC3200MOD.P30 (30_GND), CC3200MOD.P32 (32_GND), CC3200MOD.P38 (38_GND), CC3200MOD.P43 (43_GND), CC3200MOD.P55 (55), CC3200MOD.P56 (56), CC3200MOD.P57 (57), CC3200MOD.P58 (58), CC3200MOD.P59 (59_GND), CC3200MOD.P60 (60_GND), CC3200MOD.P61 (61_GND), CC3200MOD.P62 (62_GND), CC3200MOD.P63 (63_GND), JP1.1 (2), R4.2, R5.2, R16.2, R32.1, U$30.GND, U$30.TAB; also elsewhere on the board
GPIO_01/PCK/FLASH_RX: CC3200MOD.P46 (46_GPIO1); also elsewhere on the board
GPIO_03/D5: CC3200MOD.P48 (48_GPIO3); also elsewhere on the board
GPIO_04/D4: CC3200MOD.P49 (49_GPIO4); also elsewhere on the board
GPIO_05/D3: CC3200MOD.P50 (50_GPIO5); also elsewhere on the board
GPIO_06/D2: CC3200MOD.P51 (51_GPIO6); also elsewhere on the board
GPIO_07/OLED_RST: CC3200MOD.P52 (52_GPIO7)
GPIO_09/EN: CC3200MOD.P54 (54_GPIO9); also elsewhere on the board
GPIO_11/MCK: CC3200MOD.P4 (4_GPIO11); also elsewhere on the board
GPIO_12/VS: CC3200MOD.P9 (9_GPIO12); also elsewhere on the board
GPIO_13/PHS: CC3200MOD.P10 (10_GPIO13); also elsewhere on the board
GPIO_14/D6: CC3200MOD.P5 (5_GPIO14); also elsewhere on the board
GPIO_15/D7: CC3200MOD.P6 (6_GPIO15); also elsewhere on the board
GPIO_16/D8: CC3200MOD.P7 (7_GPIO16); also elsewhere on the board
GPIO_17/D9: CC3200MOD.P8 (8_GPIO17); also elsewhere on the board
GSPI_CS: CC3200MOD.P44 (44_GPIO0)
GSPI_MISO: CC3200MOD.P42 (42_GPIO30)
I2C_SCL/JTAG_TDI: CC3200MOD.P12 (12JTAG_TDI), JP3.4; also elsewhere on the board
I2C_SDA/JTAG_TDO: CC3200MOD.P18 (18_JTAG_TDO), JP3.3; also elsewhere on the board
JTAG_TCK: CC3200MOD.P21 (21_JTAG_TCK), JP3.2
JTAG_TMS: CC3200MOD.P22 (22_JTAP_TMS), JP3.1, R4.1
MCU_RF: CC3200MOD.P31 (31_RF_BG), L1.2
MICOUT/FLASH_TX: CC3200MOD.P47 (47_GPO2), JP3.5; also elsewhere on the board
unnamed: ANT_PAD.FEED2 (FEED), C33.1, L1.1
N_RESET: CC3200MOD.P35 (35_N_RESET), JP3.7
REGFB: C26.2, R31.1, R32.2, U$30.NR/FB
SOP0: CC3200MOD.P34 (34_SOP0), R5.1, SOP0.1
SOP2: CC3200MOD.P23 (23_SOP2), R16.1, SOP2.1
VBATT: C25.1, JP1.2 (1), U$30.EN, U$30.IN (VIN)
VCC: C26.1, C27.1, CC3200MOD.P36 (36_VBAT_DCDC_ANA), CC3200MOD.P37 (37_VBAT_DCDC_PA), CC3200MOD.P39 (39_VDD_ANA2), CC3200MOD.P40 (40_VBAT_DCDC_DIG_IO), R31.2, SOP0.2, SOP2.2, U$30.OUT (VOUT); also elsewhere on the board

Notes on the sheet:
Antenna
TODO: add battery connector

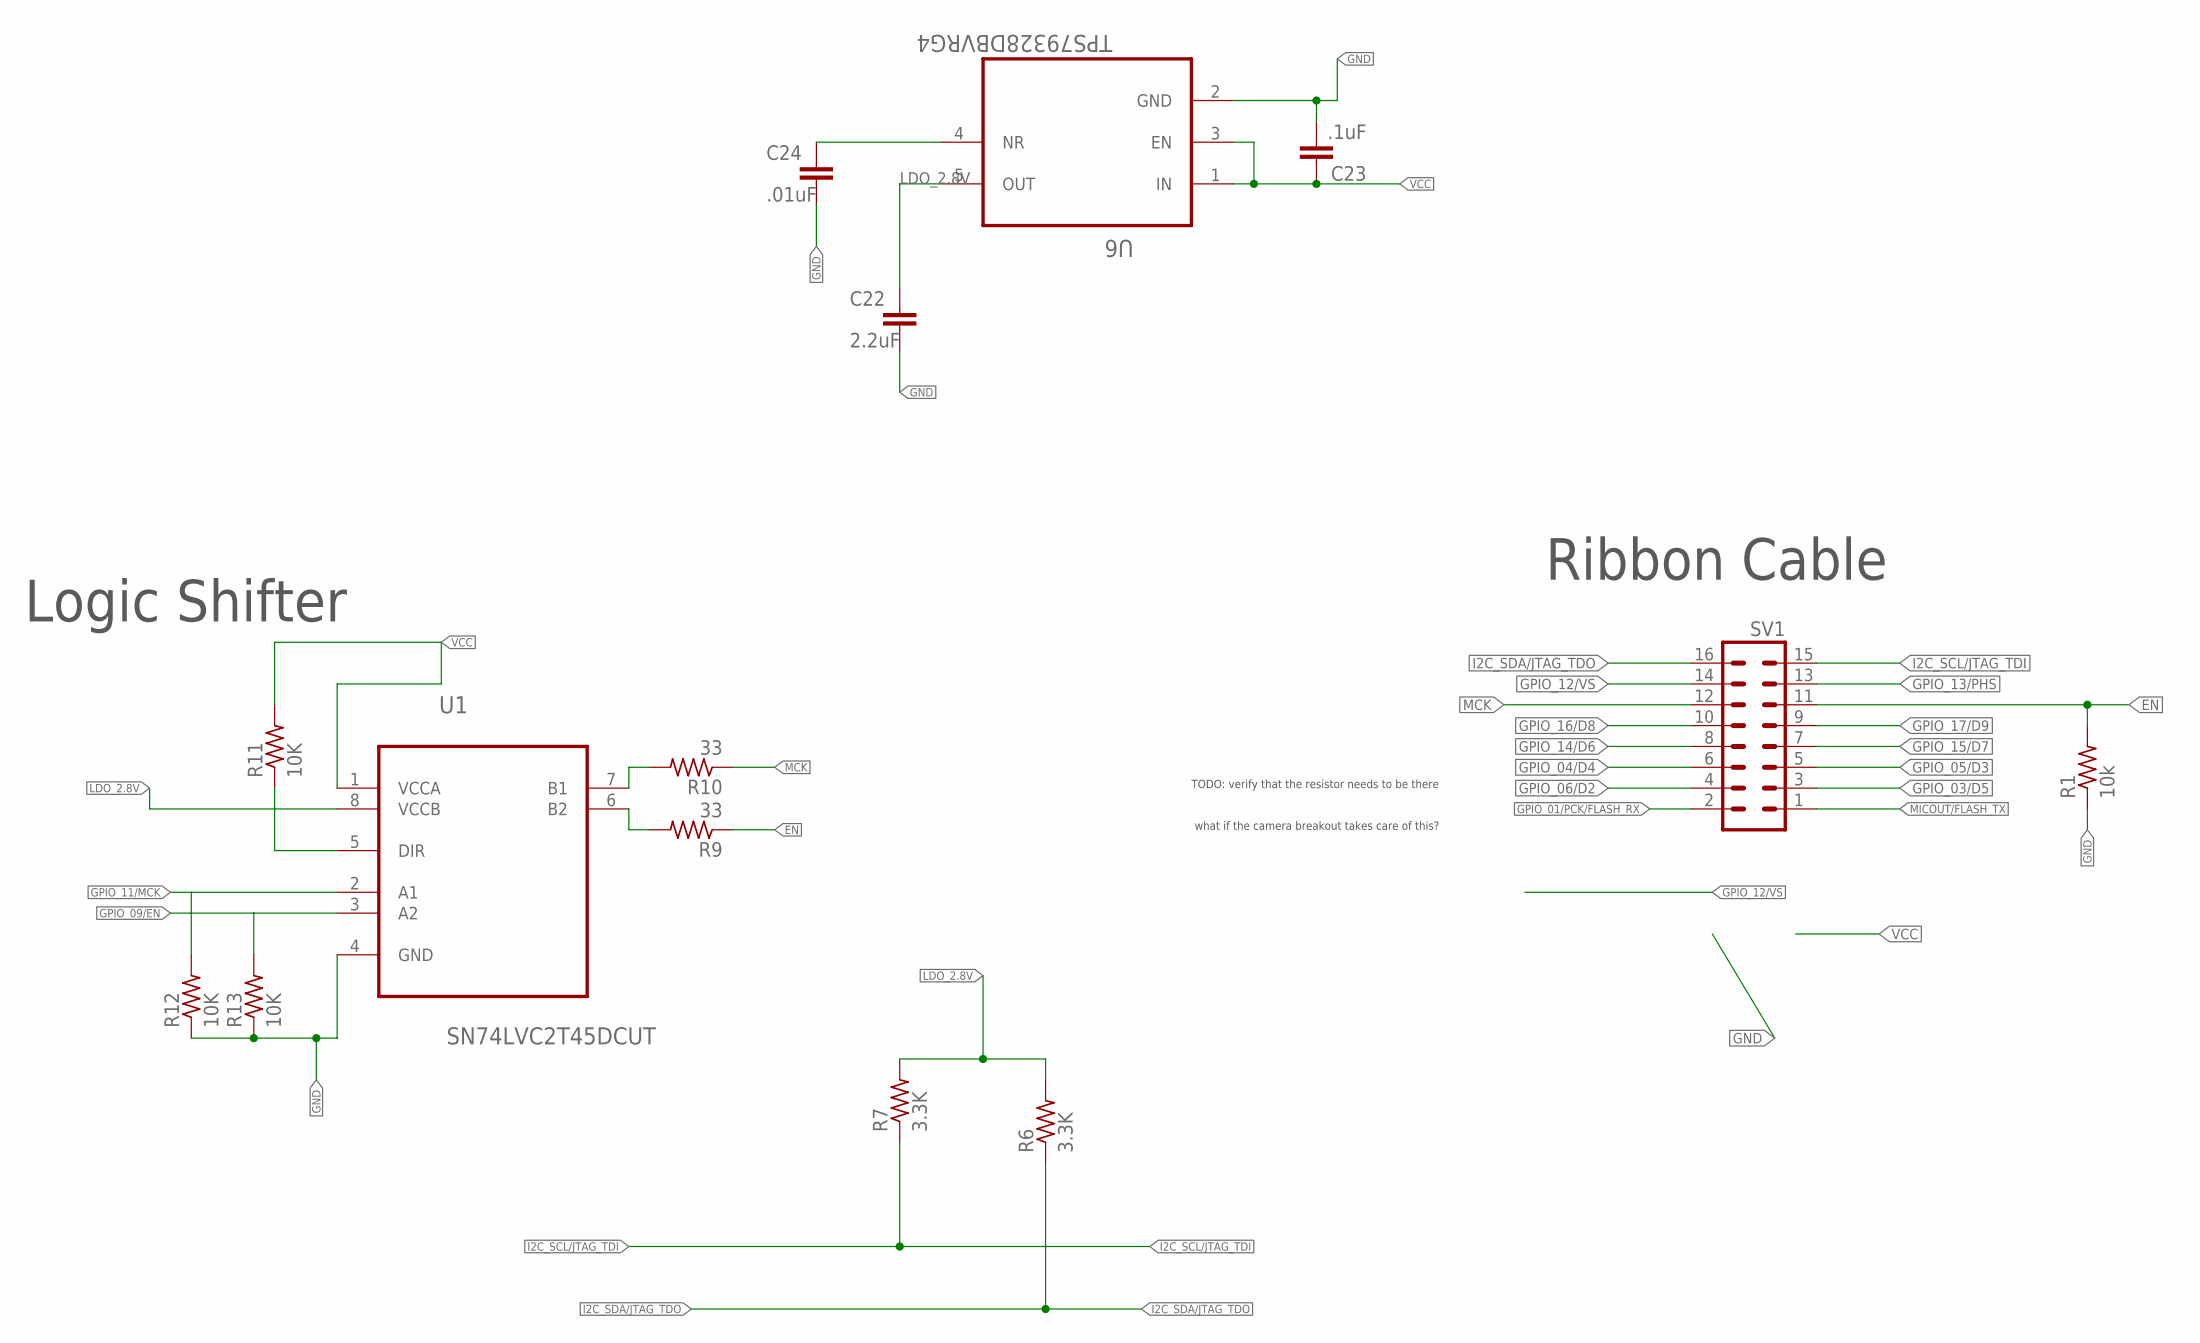
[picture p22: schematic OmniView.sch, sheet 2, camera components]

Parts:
C22: 2.2uF; C0603
C23: .1uF; C0603
C24: .01uF; C0603
R1: 10k; R0603
R6, R7: 3.3K; R0603
R9, R10: 33; R0603
R11, R12, R13: 10K; R0603
SV1: 16P
U1: SN74LVC2T45DCUT; SOP50P310X90-8N
U6: TPS79328DBVRG4; SOT95P280X145-5N

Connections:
EN: R1.2, R9.1, SV1.11
GND: C22.2, C23.2, C24.2, R1.1, R12.1, R13.1, U1.4 (GND), U6.2 (GND); also elsewhere on the board
GPIO_01/PCK/FLASH_RX: SV1.2; also elsewhere on the board
GPIO_03/D5: SV1.3; also elsewhere on the board
GPIO_04/D4: SV1.6; also elsewhere on the board
GPIO_05/D3: SV1.5; also elsewhere on the board
GPIO_06/D2: SV1.4; also elsewhere on the board
GPIO_09/EN: R13.2, U1.3 (A2); also elsewhere on the board
GPIO_11/MCK: R12.2, U1.2 (A1); also elsewhere on the board
GPIO_12/VS: SV1.14; also elsewhere on the board
GPIO_13/PHS: SV1.13; also elsewhere on the board
GPIO_14/D6: SV1.8; also elsewhere on the board
GPIO_15/D7: SV1.7; also elsewhere on the board
GPIO_16/D8: SV1.10; also elsewhere on the board
GPIO_17/D9: SV1.9; also elsewhere on the board
I2C_SCL/JTAG_TDI: R7.1, SV1.15; also elsewhere on the board
I2C_SDA/JTAG_TDO: R6.1, SV1.16; also elsewhere on the board
LDO_2.8V: C22.1, R6.2, R7.2, U1.8 (VCCB), U6.5 (OUT)
MCK: R10.1, SV1.12
MICOUT/FLASH_TX: SV1.1; also elsewhere on the board
unnamed: R11.1, U1.5 (DIR)
unnamed: C24.1, U6.4 (NR)
unnamed: R10.2, U1.7 (B1)
unnamed: R9.2, U1.6 (B2)
VCC: C23.1, R11.2, U1.1 (VCCA), U6.1 (IN), U6.3 (EN); also elsewhere on the board

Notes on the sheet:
Ribbon Cable
Logic Shifter
what if the camera breakout takes care of this?
TODO: verify that the resistor needs to be there

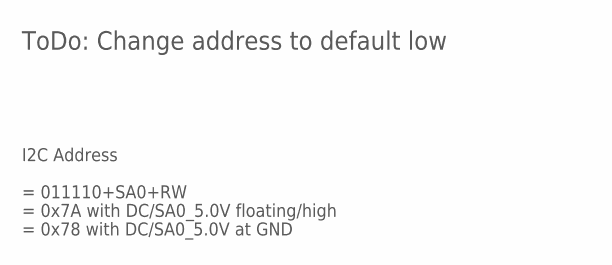
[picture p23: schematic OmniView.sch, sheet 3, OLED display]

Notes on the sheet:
= 011110+SA0+RW
= 0x7A with DC/SA0_5.0V floating/high
= 0x78 with DC/SA0_5.0V at GND
I2C Address
ToDo: Change address to default low

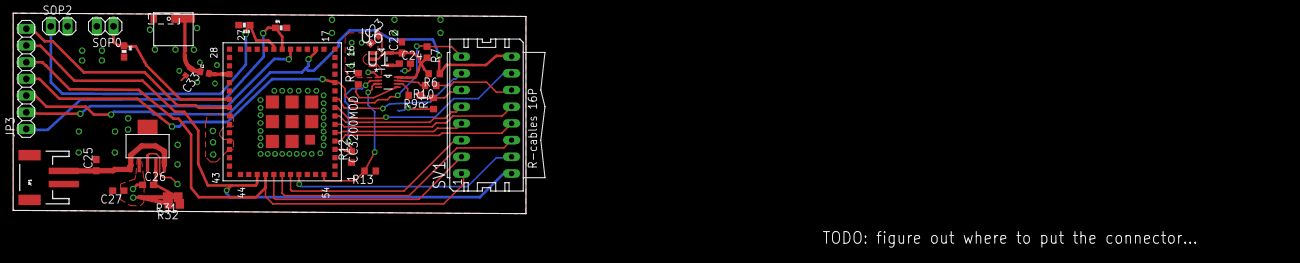
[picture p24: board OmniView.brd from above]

Board: 4 copper layers, 78.0 x 30.5 mm, 31 parts (0 on the bottom side), 34 nets.

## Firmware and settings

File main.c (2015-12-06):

#include <stdio.h>
#include <stdlib.h>
#include <string.h>

#include "osi.h"

/* DRIVERLIB INCLUDES */
#include "hw_memmap.h"
#include "hw_common_reg.h"
#include "hw_types.h"
#include "hw_ints.h"
#include "interrupt.h"
#include "prcm.h"
#include "rom.h"
#include "rom_map.h"
#include "uart.h"
#include "utils.h"
#include "systick.h"
#include "pin.h"
#include "simplelink.h"

#ifndef NOTERM
	#include "uart_if.h"
#endif
#include "udma_if.h"

#include "common.h"
#include "pinmux.h"

#include "mode.h"

//*****************************************************************************
//                      MACRO DEFINITIONS
//*****************************************************************************
#define SPAWN_TASK_PRIORITY     9
#define MAX_MSG_LENGTH 16

#define FACE_RECOGNITION_TASK_NAME "FaceRecognitionTask"
#define FACE_RECOGNITION_TASK_STACK_SIZE 8192
#define FACE_RECOGNITION_TASK_PRIORITY 2

/* Prototypes */
static void InitializeBoard();

// The queue used to send strings to the task1.
OsiMsgQ_t MsgQ;

/* We are using this for FREERTOS */
extern void (* const g_pfnVectors[])(void);

// EFFECTS: Initializes the board.
static void InitializeBoard()
{
	MAP_IntVTableBaseSet((unsigned long)&g_pfnVectors[0]);

	// Enable Processor
	MAP_IntMasterEnable();
	MAP_IntEnable(FAULT_SYSTICK);

	PRCMCC3200MCUInit();
}

int main()
{
    InitializeBoard();

	// Start the SimpleLink Host
	long lRetVal = VStartSimpleLinkSpawnTask(SPAWN_TASK_PRIORITY);
	if(lRetVal < 0)
	{
		ERR_PRINT(lRetVal);
		LOOP_FOREVER();
	}

	osi_TaskCreate(FaceRecognitionMode, FACE_RECOGNITION_TASK_NAME, FACE_RECOGNITION_TASK_STACK_SIZE,
					NULL, FACE_RECOGNITION_TASK_PRIORITY, NULL);

    // Start the task scheduler
    osi_start();

    return 0;
}

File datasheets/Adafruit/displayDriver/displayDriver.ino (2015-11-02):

void loop() {
  
}
#include <SPI.h>
#include <Wire.h>
//#include <Adafruit_GFX.h>
//#include <Adafruit_SSD1306.h>

#include "display_driver.h"

#define MAX_NAMES_ALLOCATED 5
#define MAX_NAME_LENGTH 15

#define NAME_TEXT_SIZE 1
#define TEXT_COLOR WHITE

char firstName[MAX_NAMES_ALLOCATED][MAX_NAME_LENGTH] = { "GARRISON", "ZHENG HAO", "TZU FEI", "LOREN", "JOHN" };
char lastName[MAX_NAMES_ALLOCATED][MAX_NAME_LENGTH] = { "BELLACK", "TAN", "YU", "WANG", "CONNOLY" };

void setup()   {                
  Serial.begin(9600);

  begin();

  // Clear the buffer.
  clearDisplay();

  // text display tests
  setTextSize(NAME_TEXT_SIZE);
  setTextColor(WHITE);
  setCursor(0,0);

  uint8_t i = 0;
  for (i = 0; i < MAX_NAMES_ALLOCATED; ++i) {
    println(firstName[i]);
    println(lastName[i]);
  }
  display();

  testscrolltext();
}

// TODO: Scrolling stuff.
void testscrolltext() {
  
  setTextSize(1);
  setTextColor(WHITE);
  setCursor(10,0);
  clearDisplay();
  println("scroll");
  display();
 
  startscrollright(0x00, 0x0F);
  delay(2000);
  stopscroll();
  delay(1000);
  startscrollleft(0x00, 0x0F);
  delay(2000);
  stopscroll();
}

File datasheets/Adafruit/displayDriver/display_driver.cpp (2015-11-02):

#include "display_driver.h"

#define HEIGHT SSD1306_LCDHEIGHT
#include <avr/pgmspace.h>
#if !defined(__SAM3X8E__) && !defined(ARDUINO_ARCH_SAMD)
 #include <util/delay.h>
#endif
#include <stdlib.h>

#ifdef __AVR__
 #include <avr/pgmspace.h>
#elif defined(ESP8266)
 #include <pgmspace.h>
#else
 #define pgm_read_byte(addr) (*(const unsigned char *)(addr))
#endif

#define ssd1306_swap(a, b) { int16_t t = a; a = b; b = t; }

#ifndef min
 #define min(a,b) ((a < b) ? a : b)
#endif

#ifdef __AVR__
 #include <avr/io.h>
 #include <avr/pgmspace.h>
#elif defined(ESP8266)
 #include <pgmspace.h>
#else
 #define PROGMEM
#endif

// Standard ASCII 5x7 font
static const unsigned char font[] PROGMEM = {
  0x00, 0x00, 0x00, 0x00, 0x00,
  0x3E, 0x5B, 0x4F, 0x5B, 0x3E,
  0x3E, 0x6B, 0x4F, 0x6B, 0x3E,
  0x1C, 0x3E, 0x7C, 0x3E, 0x1C,
  0x18, 0x3C, 0x7E, 0x3C, 0x18,
  0x1C, 0x57, 0x7D, 0x57, 0x1C,
  0x1C, 0x5E, 0x7F, 0x5E, 0x1C,
  0x00, 0x18, 0x3C, 0x18, 0x00,
  0xFF, 0xE7, 0xC3, 0xE7, 0xFF,
  0x00, 0x18, 0x24, 0x18, 0x00,
  0xFF, 0xE7, 0xDB, 0xE7, 0xFF,
  0x30, 0x48, 0x3A, 0x06, 0x0E,
  0x26, 0x29, 0x79, 0x29, 0x26,
  0x40, 0x7F, 0x05, 0x05, 0x07,
  0x40, 0x7F, 0x05, 0x25, 0x3F,
  0x5A, 0x3C, 0xE7, 0x3C, 0x5A,
  0x7F, 0x3E, 0x1C, 0x1C, 0x08,
  0x08, 0x1C, 0x1C, 0x3E, 0x7F,
  0x14, 0x22, 0x7F, 0x22, 0x14,
  0x5F, 0x5F, 0x00, 0x5F, 0x5F,
  0x06, 0x09, 0x7F, 0x01, 0x7F,
  0x00, 0x66, 0x89, 0x95, 0x6A,
  0x60, 0x60, 0x60, 0x60, 0x60,
  0x94, 0xA2, 0xFF, 0xA2, 0x94,
  0x08, 0x04, 0x7E, 0x04, 0x08,
  0x10, 0x20, 0x7E, 0x20, 0x10,
  0x08, 0x08, 0x2A, 0x1C, 0x08,
  0x08, 0x1C, 0x2A, 0x08, 0x08,
  0x1E, 0x10, 0x10, 0x10, 0x10,
  0x0C, 0x1E, 0x0C, 0x1E, 0x0C,
  0x30, 0x38, 0x3E, 0x38, 0x30,
  0x06, 0x0E, 0x3E, 0x0E, 0x06,
  0x00, 0x00, 0x00, 0x00, 0x00,
  0x00, 0x00, 0x5F, 0x00, 0x00,
  0x00, 0x07, 0x00, 0x07, 0x00,
  0x14, 0x7F, 0x14, 0x7F, 0x14,
  0x24, 0x2A, 0x7F, 0x2A, 0x12,
  0x23, 0x13, 0x08, 0x64, 0x62,
  0x36, 0x49, 0x56, 0x20, 0x50,
  0x00, 0x08, 0x07, 0x03, 0x00,
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
  0x22, 0x54, 0x54, 0x78, 0x42, // a-umlaut
  0x21, 0x55, 0x54, 0x78, 0x40,
  0x20, 0x54, 0x55, 0x79, 0x40,
  0x0C, 0x1E, 0x52, 0x72, 0x12,
  0x39, 0x55, 0x55, 0x55, 0x59,
  0x39, 0x54, 0x54, 0x54, 0x59,
  0x39, 0x55, 0x54, 0x54, 0x58,
  0x00, 0x00, 0x45, 0x7C, 0x41,
  0x00, 0x02, 0x45, 0x7D, 0x42,
  0x00, 0x01, 0x45, 0x7C, 0x40,
  0x7D, 0x12, 0x11, 0x12, 0x7D, // A-umlaut
  0xF0, 0x28, 0x25, 0x28, 0xF0,
  0x7C, 0x54, 0x55, 0x45, 0x00,
  0x20, 0x54, 0x54, 0x7C, 0x54,
  0x7C, 0x0A, 0x09, 0x7F, 0x49,
  0x32, 0x49, 0x49, 0x49, 0x32,
  0x3A, 0x44, 0x44, 0x44, 0x3A, // o-umlaut
  0x32, 0x4A, 0x48, 0x48, 0x30,
  0x3A, 0x41, 0x41, 0x21, 0x7A,
  0x3A, 0x42, 0x40, 0x20, 0x78,
  0x00, 0x9D, 0xA0, 0xA0, 0x7D,
  0x3D, 0x42, 0x42, 0x42, 0x3D, // O-umlaut
  0x3D, 0x40, 0x40, 0x40, 0x3D,
  0x3C, 0x24, 0xFF, 0x24, 0x24,
  0x48, 0x7E, 0x49, 0x43, 0x66,
  0x2B, 0x2F, 0xFC, 0x2F, 0x2B,
  0xFF, 0x09, 0x29, 0xF6, 0x20,
  0xC0, 0x88, 0x7E, 0x09, 0x03,
  0x20, 0x54, 0x54, 0x79, 0x41,
  0x00, 0x00, 0x44, 0x7D, 0x41,
  0x30, 0x48, 0x48, 0x4A, 0x32,
  0x38, 0x40, 0x40, 0x22, 0x7A,
  0x00, 0x7A, 0x0A, 0x0A, 0x72,
  0x7D, 0x0D, 0x19, 0x31, 0x7D,
  0x26, 0x29, 0x29, 0x2F, 0x28,
  0x26, 0x29, 0x29, 0x29, 0x26,
  0x30, 0x48, 0x4D, 0x40, 0x20,
  0x38, 0x08, 0x08, 0x08, 0x08,
  0x08, 0x08, 0x08, 0x08, 0x38,
  0x2F, 0x10, 0xC8, 0xAC, 0xBA,
  0x2F, 0x10, 0x28, 0x34, 0xFA,
  0x00, 0x00, 0x7B, 0x00, 0x00,
  0x08, 0x14, 0x2A, 0x14, 0x22,
  0x22, 0x14, 0x2A, 0x14, 0x08,
  0x55, 0x00, 0x55, 0x00, 0x55, // #176 (25% block) missing in old code
  0xAA, 0x55, 0xAA, 0x55, 0xAA, // 50% block
  0xFF, 0x55, 0xFF, 0x55, 0xFF, // 75% block
  0x00, 0x00, 0x00, 0xFF, 0x00,
  0x10, 0x10, 0x10, 0xFF, 0x00,
  0x14, 0x14, 0x14, 0xFF, 0x00,
  0x10, 0x10, 0xFF, 0x00, 0xFF,
  0x10, 0x10, 0xF0, 0x10, 0xF0,
  0x14, 0x14, 0x14, 0xFC, 0x00,
  0x14, 0x14, 0xF7, 0x00, 0xFF,
  0x00, 0x00, 0xFF, 0x00, 0xFF,
  0x14, 0x14, 0xF4, 0x04, 0xFC,
  0x14, 0x14, 0x17, 0x10, 0x1F,
  0x10, 0x10, 0x1F, 0x10, 0x1F,
  0x14, 0x14, 0x14, 0x1F, 0x00,
  0x10, 0x10, 0x10, 0xF0, 0x00,
  0x00, 0x00, 0x00, 0x1F, 0x10,
  0x10, 0x10, 0x10, 0x1F, 0x10,
  0x10, 0x10, 0x10, 0xF0, 0x10,
  0x00, 0x00, 0x00, 0xFF, 0x10,
  0x10, 0x10, 0x10, 0x10, 0x10,
  0x10, 0x10, 0x10, 0xFF, 0x10,
  0x00, 0x00, 0x00, 0xFF, 0x14,
  0x00, 0x00, 0xFF, 0x00, 0xFF,
  0x00, 0x00, 0x1F, 0x10, 0x17,
  0x00, 0x00, 0xFC, 0x04, 0xF4,
  0x14, 0x14, 0x17, 0x10, 0x17,
  0x14, 0x14, 0xF4, 0x04, 0xF4,
  0x00, 0x00, 0xFF, 0x00, 0xF7,
  0x14, 0x14, 0x14, 0x14, 0x14,
  0x14, 0x14, 0xF7, 0x00, 0xF7,
  0x14, 0x14, 0x14, 0x17, 0x14,
  0x10, 0x10, 0x1F, 0x10, 0x1F,
  0x14, 0x14, 0x14, 0xF4, 0x14,
  0x10, 0x10, 0xF0, 0x10, 0xF0,
  0x00, 0x00, 0x1F, 0x10, 0x1F,
  0x00, 0x00, 0x00, 0x1F, 0x14,
  0x00, 0x00, 0x00, 0xFC, 0x14,
  0x00, 0x00, 0xF0, 0x10, 0xF0,
  0x10, 0x10, 0xFF, 0x10, 0xFF,
  0x14, 0x14, 0x14, 0xFF, 0x14,
  0x10, 0x10, 0x10, 0x1F, 0x00,
  0x00, 0x00, 0x00, 0xF0, 0x10,
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
  0xFC, 0x4A, 0x4A, 0x4A, 0x34, // sharp-s or beta
  0x7E, 0x02, 0x02, 0x06, 0x06,
  0x02, 0x7E, 0x02, 0x7E, 0x02,
  0x63, 0x55, 0x49, 0x41, 0x63,
  0x38, 0x44, 0x44, 0x3C, 0x04,
  0x40, 0x7E, 0x20, 0x1E, 0x20,
  0x06, 0x02, 0x7E, 0x02, 0x02,
  0x99, 0xA5, 0xE7, 0xA5, 0x99,
  0x1C, 0x2A, 0x49, 0x2A, 0x1C,
  0x4C, 0x72, 0x01, 0x72, 0x4C,
  0x30, 0x4A, 0x4D, 0x4D, 0x30,
  0x30, 0x48, 0x78, 0x48, 0x30,
  0xBC, 0x62, 0x5A, 0x46, 0x3D,
  0x3E, 0x49, 0x49, 0x49, 0x00,
  0x7E, 0x01, 0x01, 0x01, 0x7E,
  0x2A, 0x2A, 0x2A, 0x2A, 0x2A,
  0x44, 0x44, 0x5F, 0x44, 0x44,
  0x40, 0x51, 0x4A, 0x44, 0x40,
  0x40, 0x44, 0x4A, 0x51, 0x40,
  0x00, 0x00, 0xFF, 0x01, 0x03,
  0xE0, 0x80, 0xFF, 0x00, 0x00,
  0x08, 0x08, 0x6B, 0x6B, 0x08,
  0x36, 0x12, 0x36, 0x24, 0x36,
  0x06, 0x0F, 0x09, 0x0F, 0x06,
  0x00, 0x00, 0x18, 0x18, 0x00,
  0x00, 0x00, 0x10, 0x10, 0x00,
  0x30, 0x40, 0xFF, 0x01, 0x01,
  0x00, 0x1F, 0x01, 0x01, 0x1E,
  0x00, 0x19, 0x1D, 0x17, 0x12,
  0x00, 0x3C, 0x3C, 0x3C, 0x3C,
  0x00, 0x00, 0x00, 0x00, 0x00  // #255 NBSP
};
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

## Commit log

2015-10-10 eagle initial commit
    initial eagle schematic commit. For now just contains the footprints of
    our devices. Still need to make power regulator.
    [OmniView.brd, OmniView.sch]
2015-10-11 schematic check-up
    did a little bit of schematic setting up
    [OmniView.brd, OmniView.sch]
2015-10-11 test pics
    [output.csv, output1.csv, output2.csv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]
2015-10-14 wireless ap is working
2015-10-16 wireless module is working
2015-10-19 added adafruit drivers
2015-10-21 schematic check-up
    initial schematic done, beginning routing
    [OmniView.brd, OmniView.sch]
2015-10-22 added display driver, not sure if working yet
2015-10-23 added better display drivers
2015-10-24 initial board push
    first revision of board is...done! This revision still needs to:
    -review antenna trace with expert
    -clean up some of the routing
    -be reviewed by non-john member of the team
    [OmniView.brd, OmniView.sch]
2015-10-31 display still has 1 more bug
    [display.c]
2015-11-02 added Arduino display module library
2015-11-05 cleaned up code and fixed i2c to use pin 16 & 17
    [pinmux.c]
2015-11-06 added camera code but cant compile
2015-11-08 small camera integration changes
2015-11-08 cleaner, but doesn't work yet
    [camera_app.c, i2cconfig.c, main.c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]
2015-11-12 fixed hard fault bug
    [mode.c]
2015-11-12 connected tcp to camera
2015-11-13 added speech recognition samples
2015-11-15 First attempt at integrating camera, networking, and display. This commit is broken and can't get through the initModules
    [camera_app.c, display.c, main.c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]
2015-11-15 prior merge not done properly, fixed
    [display.c]
2015-11-15 Still trying to get just camera working
2015-11-15 Camera+Networking works, except when diplay attached (even if display software not called)
2015-11-19 added button interrupt code
2015-11-19 added better descriptions for the button and microphone interrupt
2015-11-21 display glitch fix
    added reset for i2c glitch fix, and also added glitch tolerance on the
    i2c bus
    [display.c, i2cconfig.c, main.c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]
2015-11-22 removed a few delays. Currently having issues running the primary loop for a long time. Will crash undeterministically after a while by going to prvTaskExitError
    [camera_app.c, main.c, mode.c]
2015-11-24 Still trying to debug the loop crashing. Narrowed it down and have debugging implemented
    [mode.c]
2015-11-29 added timer interrupt interface
2015-12-01 STABLE. Fixed networking bug. Primary mode runs infinitly now
    [main.c, mode.c]
2015-12-01 Integrated button interrupt code
2015-12-02 updated display reset pin to PCB pinout
2015-12-03 Added infrastructure for secondary mode and integrated button and mic code. Currently button interrupts are not triggering and mic code is untested
2015-12-05 changed camera intialization and added debug information
2015-12-05 PCB changes
    added some small changes for migrating from dev board to PCB
2015-12-06 STABLE. Primary mode up and running perfectly on the pcb!
2015-12-10 updated display offset for PCB
2015-12-10 fixed indent bug for display
    [display.c]
2015-12-10 Added possible restart fix. Untested
    [mode.c]

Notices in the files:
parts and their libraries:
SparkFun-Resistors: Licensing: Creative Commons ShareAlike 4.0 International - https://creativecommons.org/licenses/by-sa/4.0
